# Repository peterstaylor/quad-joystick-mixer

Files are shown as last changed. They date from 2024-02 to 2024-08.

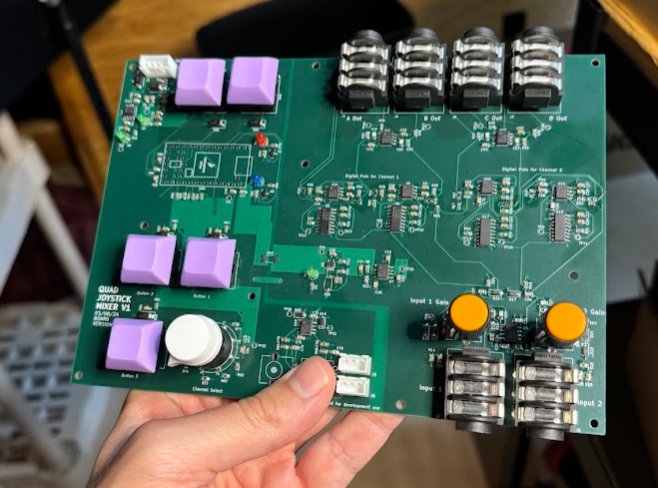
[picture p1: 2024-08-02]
mixer.png

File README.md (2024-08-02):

# quad-joystick-mixer
This is a README for the quadrophonic joystick mixer design

# Hardware
## IO Summary: 
### Digital Interface: 
We have two I2C interfaces which is more than we techincally need for this board, but is how many we'll need if we go to 8 inputs to to the mixer. Each input requires two digital pots, so that's 16 total digital pots and each i2c interface can only support up to 8 digital pots

- I2C 0 controls the digital pots for input channel 1
- I2C 1 controls the digital pots for input channel 2

### Outputs: 
I included LED indicators to help in development and for general app use as needed: 
- Red LED Indicator = Teensy Digital Output 2
- Blue LED Indicator = Teensy Digital Output 3

### Inputs: 
#### Buttons: 
There are three buttons that can be used however needed. Three might be more than we actually need, but I had spare I/O
- Button 1 = Teensy Digital Input 7
- Button 2 = Teensy Digital Input 8
- Button 3 = Teensy Digital Input 7

I've also bought out the PROGRAM and POWER pins on the Teensy to buttons. I don't think we need these, but I wasn't sure so I included them in this first revision. 

#### Analaog Inputs: 
- Encoder channel selection input = Teensy Analog Input 14
    - I used an analog input for channel selection instead of something digital so I could save I/O on the micro. If this interface is flaky we can switch to digital for the next spin of the board
- Joystick AB Control Input = Teensy Analog Input 15
- Joystick CD Control Input = Teensy Analog Input 20 

## V1 to V2 Change Log: 
- [] Use attenuator as front-end gain control instead of amplifier feedback gain
- [] Add additional filtering to VCC and VDD rails 
- [] upgrade to lower noise op-amps
- [] don't route the dang i2c nets over a cut in the ground plane!!! 
- [] Add analog filtering and buffering to the input path from the encoder to smoothe out readings
- [] revisit output gain and mixing
- [] Add six more analog inputs for a total of 8 inputs 
- [] Perform electromechanical integration work once the design is working

# Firmware
## Teensy 
- Link to Teensy tutorial: https://www.pjrc.com/teensy/tutorial.html
- Link to how to set up a portable install of the Arduino IDE: https://docs.arduino.cc/software/ide-v1/tutorials/PortableIDE/
    - I had to set up a portable install to get all the teensy libraries to install correctly and compile the code

## Board Level Test (BLT) Code
This code is written to exercise the I/O on the system in a simple way just to verify the hardware

### Major Board Level Test Functions: 
- checkBLTTransition(): 
    - This function looks for the user to press down button 1 for a certain amount of time and then puts the board in BLT mode
- flash(): 
    - flashes both LEDs the desired number of times
    - input argument is an int setting the number of flashes
- analogReadToChannelCount: 
    - input argument is an int return from reading the encoder ADC channel
    - output is the channel of the mixer 1 through 8
    - use this function to determine what channel the user is trying to control
- binaryLED: 
    - input is int of channel count 
    - i used this for BLT to verify i was iterating through the channels visually
- calibrateJoystick: 
    - I'm not using this function right now but will probably be useful for application as I've already seen that there are inconsistencies between the two joysticks I have

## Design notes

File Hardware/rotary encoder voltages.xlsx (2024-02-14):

Step | 0.4125 |  | Pull Up | 10000
Input | Voltage | Pull-down |  | Selected (kOhms) |  | 2% toleranced | Max Voltage Cutoff
1 | 0.4125 | 1428.571429 |  | 1.43 | 1.4586 | 1458.6 | 0.4275291777 | 0.4275291777
2 | 0.825 | 3333.333333 |  | 3.32 | 3.3864 | 3386.4 | 0.8474731542 | 0.4199439765
3 | 1.2375 | 6000 |  | 6.04 | 6.1608 | 6160.8 | 1.273785775 | 0.426312621
4 | 1.65 | 10000 |  | 10 | 10.2 | 10200 | 1.683 | 0.4092142249
5 | 2.0625 | 16666.66667 |  | 16.5 | 16.83 | 16830 | 2.085580173 | 0.4025801727
6 | 2.475 | 30000 |  | 30.1 | 30.702 | 30702 | 2.501520913 | 0.4159407398
7 | 2.8875 | 70000 |  | 71.5 | 72.93 | 72930 | 2.90908981 | 0.4075688977
8 | 3.3 | Open
rotary logic
if voltage is less than | the channel is | 1% resistor value
0.428 V | 1 | 1.43 kOhm
0.847 V | 2 | 3.32 kOhm
1.274 V | 3 | 6.04 kOhm
1.683 V | 4 | 10.00 kOhm
2.086 V | 5 | 16.50 kOhm
2.502 V | 6 | 30.10 kOhm
2.909 V | 7 | 71.50 kOhm
3.300 V | 8 | Open

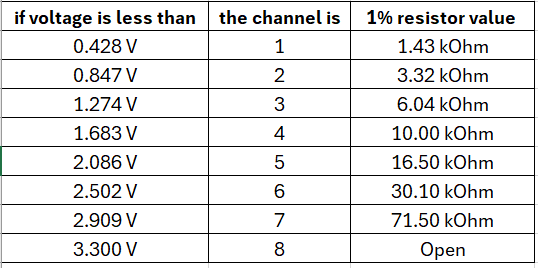
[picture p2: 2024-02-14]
Hardware/rotary.png

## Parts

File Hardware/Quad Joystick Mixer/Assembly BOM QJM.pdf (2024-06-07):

Reference | Qty | Value | Footprint
C1, C10, C26, C29, C75, C76 | 6 10uF | | 0805
C2, C5, C8, C9, C11, C13, C16, C30, C31, C34-C36, C38-C44, C53, C54, C56, C57, C60, C62, C63, C67-C74, C77, C78, C80-C86 | 43 0.1uF | | 0805
C25, C27 | 2 10pF | | 0805
C3, C4, C6, C12, C15, C24, C28, C32, C33, C37, C45-C48, C55, C58, C59, C65, C66 | 19 1uF | | 0805
C49-C52 | 4 330pF | | 0805
D1, D5 | 2 B350 | | SMA
D12-D15 | 4 MMSZ5222BT1G | | SOD-123
D16, D17 | 2 BZT52C4V7-13-F | | SOD-123
D18, D19 | 2 DDZ9684-7 | | SOD-123
D22-D26 | 5 SMAJ5.0A | | SMA
D7, D9, D11, D20, D21 | 5 LED | | 3.0mm LED
J1 | 1 XH-B4B-XH | | JST-4
J2-J7 | 6 NMJ6HCD | | NMJ6HCD
J8, J9 | 2 XH-A | | JST-3
NT1 | 1 NetTie_2 | | Net tie
Q1, Q2 | 2 2N7002 | | SOT-23
R14, R19, R24, R28-R31, R48, R50, R53, R58, R61 | 12 100k | | 0805
R15, R18, R66-R69 | 6 4.7k | | 0805
R16, R17 | 2 470R | | 0805
R20 | 1 4.7R | | 0805
R3 | 1 3k | | 0805
R34, R35, R38, R39 | 4 1k | | 0805
R40, R85-R88 | 5 DNA | | -- mixed values --
R62 | 1 1.43k | | 0805
R63 | 1 3.32k | | 0805
R64, R65 | 2 100R | | 0805
R73 | 1 6.04k | | 0805
R75 | 1 16.5k | | 0805
R76 | 1 30.1k | | 0805
R77 | 1 71.5k | | 0805
R78, R80 | 2 200R | | 0805
R8, R23, R32, R33, R36, R37 | 6 20k | | 0805
R9, R11, R21, R22, R25-R27, R44-R47, R49, R51, R52, R56, R57, R59, R60, R72, R74, R79, R81-R84 | 25 10k | | 0805
RV1, RV2 | 2 500kA | | 9mm pot
RV3, RV4 | 2 10k-B | | 9mm pot

Reference | Qty | Value | Footprint
SW2 | 1 Stompbox 1P8T Rotary | | 1p8t rotary
SW3-SW7 | 5 Cherry MX | | Cherry MX
TP1-TP23 | 23 TestPoint | | TP
U1 | 1 L78M12ACDT-TR | | TO-252-2
U2 | 1 MC79L12ABDG | | SOIC-8
U20 | 1 Teensy4.0 | | Teensy
U4, U6, U7, U10-U12, U14, U16, U19 | 9 TL072 | | SOIC-8
U5 | 1 MCP1755T-5002E/OT | | SOT-23-5
U8, U9, U13, U17 | 4 DS1881Z-050+ | | SOIC-16

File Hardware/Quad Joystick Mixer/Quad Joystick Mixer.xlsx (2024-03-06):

Assembly Count | 1
Reference | Value | Qty | Ext Qty | Footprint | Current | DK PN | MPN | Power | Source | V | Unit Cost | Ext Cost
C1, C7, C10, C21, C26, C29, C75, C76 | 10uF | 8 | 8 | Capacitor_SMD:C_0805_2012Metric_Pad1.18x1.45mm_HandSolder |  | 490-GRM21BR61H106KE43KCT-ND | GRM21BR61H106KE43K |  | DK |  | 0.224 | 1.792
C2, C8, C9, C11, C16, C19, C20, C22, C30, C31, C34-C36, C38-C44, C53, C54, C56, C57, C60, C62, C63, C67-C74, C77, C78, C80-C86 | 0.1uF | 44 | 44 | Capacitor_SMD:C_0805_2012Metric_Pad1.18x1.45mm_HandSolder |  | 1276-1003-1-ND | CL21B104KBCNNNC |  | DK |  | 0.024 | 1.056
C3, C4, C12, C13 | 2200uF | 4 | 4 | Capacitor_THT:C_Radial_D16.0mm_H25.0mm_P7.50mm |  | 1189-2266-ND | 35ZLH2200MEFC16X25 |  | DK | 50V | 1.63 | 6.52
C5, C14 | 100uF | 2 | 2 | Capacitor_THT:CP_Radial_D8.0mm_P3.50mm |  | 1189-2327-ND | 50ZLH100MEFC8X11.5 |  | DK | 50V | 0.39 | 0.78
C6, C15, C24, C28, C32, C33, C37, C45-C48, C55, C58, C59, C65, C66 | 1uF | 16 | 16 | Capacitor_SMD:C_0805_2012Metric_Pad1.18x1.45mm_HandSolder |  | 1276-1029-1-ND | CL21B105KBFNNNE |  | DK | -- mixed values -- | 0.075 | 1.2
C17, C18 | 22uF | 2 | 2 | Capacitor_SMD:C_1206_3216Metric_Pad1.33x1.80mm_HandSolder |  | 445-8045-1-ND | C3216X5R1V226M160AC |  | DK |  | 0.86 | 1.72
C23 | 100pF | 1 | 1 | Capacitor_SMD:C_0805_2012Metric_Pad1.18x1.45mm_HandSolder |  | 1276-1014-1-ND | CL21C101JBANNNC |  | DK |  | 0.1 | 0.1
C25, C27 | 10pF | 2 | 2 | Capacitor_SMD:C_0805_2012Metric_Pad1.18x1.45mm_HandSolder |  | 399-C0805C100J5GAC7800CT-ND | C0805C100J5GAC7800 |  | DK | 50V | 0.1 | 0.2
C49-C52 | 330pF | 4 | 4 | Capacitor_SMD:C_0805_2012Metric_Pad1.18x1.45mm_HandSolder |  | 399-C0805C331J5GAC7800CT-ND | C0805C331J5GAC7800 |  | DK |  | 0.1 | 0.4
D1-D6, D10 | B350 | 7 | 7 | Diode_SMD:D_SMA_Handsoldering |  | B350A-FDICT-ND | B350A-13-F |  | DK |  | 0.377 | 2.639
D12-D15 | MMSZ5222BT1G | 4 | 4 | Diode_SMD:D_SOD-123 |  | MMSZ5222BT1GOSCT-ND | MMSZ5222BT1G |  | DK |  | 0.23 | 0.92
D16, D17 | BZT52C4V7-13-F | 2 | 2 | Diode_SMD:D_SOD-123 |  | BZT52C4V7-13FDICT-ND | BZT52C4V7-13-F |  | DK |  | 0.21 | 0.42
D18, D19 | DDZ9684-7 | 2 | 2 | Diode_SMD:D_SOD-123 |  | DDZ9684-7DICT-ND | DDZ9684-7 |  | DK |  | 0.28 | 0.56
D22-D26 | SMAJ5.0A | 5 | 5 | Diode_SMD:D_SMA |  | SMAJ5.0A-FDICT-ND | SMAJ5.0A-13-F |  | DK |  | 0.39 | 1.95
L4 | 10uH | 1 | 1 | Inductor_SMD:L_Abracon_ASPI-0630LR | 1.5A | ASPI-0630LR-100M-T15CT-ND | ASPI-0630LR-100M-T15 |  | DK |  | 0.72 | 0.72
Q1, Q2 | 2N7002 | 2 | 2 | Package_TO_SOT_SMD:SOT-23 |  | 2N7002-TPMSCT-ND | 2N7002-TP |  | DK |  | 0.17 | 0.34
R1, R2, R6, R7 | 0.5R | 4 | 4 | Resistor_SMD:R_2512_6332Metric_Pad1.40x3.35mm_HandSolder |  | CSRN2512FKR500CT-ND | CSRN2512FKR500 | 2W | DK |  | 0.5 | 2
R3, R10 | 3k | 2 | 2 | Resistor_SMD:R_0805_2012Metric_Pad1.20x1.40mm_HandSolder |  | A126368CT-ND | CRG0805F3K0 |  | DK |  | 0.1 | 0.2
R4 | 270R | 1 | 1 | Resistor_SMD:R_0805_2012Metric_Pad1.20x1.40mm_HandSolder |  | 311-270CRCT-ND | RC0805FR-07270RL |  | DK |  | 0.1 | 0.1
R5 | 2.32k | 1 | 1 | Resistor_SMD:R_0805_2012Metric_Pad1.20x1.40mm_HandSolder |  | RMCF0805FT2K32CT-ND | RMCF0805FT2K32 |  | DK |  | 0.1 | 0.1
R8, R23, R32, R33, R36, R37 | 20k | 6 | 6 | Resistor_SMD:R_0805_2012Metric_Pad1.20x1.40mm_HandSolder |  | RMCF0805FT20K0CT-ND | RMCF0805FT20K0 |  | DK |  | 0.02 | 0.12
R9, R11, R21, R22, R25-R27, R44-R47, R49, R51, R52, R56, R57, R59, R60, R72, R74, R79, R81-R84 | 10k | 25 | 25 | Resistor_SMD:R_0805_2012Metric_Pad1.20x1.40mm_HandSolder |  | RMCF0805JT10K0CT-ND | RMCF0805JT10K0 |  | DK |  | 0.0104 | 0.26
R12 | 158k | 1 | 1 | Resistor_SMD:R_0805_2012Metric_Pad1.20x1.40mm_HandSolder |  | 311-158KCRCT-ND | RES 158K OHM 1% 1/8W 0805 |  | DK |  | 0.1 | 0.1
R13 | 30k | 1 | 1 | Resistor_SMD:R_0805_2012Metric_Pad1.20x1.40mm_HandSolder |  | RMCF0805JT30K0CT-ND | RMCF0805JT30K0 |  | DK |  | 0.1 | 0.1
R14, R19, R24, R28-R31, R48, R50, R53, R58, R61 | 100k | 12 | 12 | Resistor_SMD:R_0805_2012Metric_Pad1.20x1.40mm_HandSolder |  | RMCF0805FT100KCT-ND | RMCF0805FT100K |  | DK |  | 0.02 | 0.24
R15, R18, R66-R69 | 4.7k | 6 | 6 | Resistor_SMD:R_0805_2012Metric_Pad1.20x1.40mm_HandSolder |  | RMCF0805JT4K70CT-ND | RMCF0805JT4K70 |  | DK |  | 0.017 | 0.102
R16, R17 | 470 | 2 | 2 | Resistor_SMD:R_0805_2012Metric_Pad1.20x1.40mm_HandSolder |  | RMCF0805FT470RCT-ND | RMCF0805FT470R |  | DK |  | 0.1 | 0.2
R20 | 4.7R | 1 | 1 | Resistor_SMD:R_2010_5025Metric_Pad1.40x2.65mm_HandSolder |  | RMCF2010FT4R70CT-ND | RMCF2010FT4R70 | 3/4W | DK |  | 0.22 | 0.22
R34, R35, R38, R39 | 1k | 4 | 4 | Resistor_SMD:R_0805_2012Metric_Pad1.20x1.40mm_HandSolder |  | RMCF0805FT1K00CT-ND | RMCF0805FT1K00 |  | DK |  | 0.1 | 0.4
R62 | 1.43k | 1 | 1 | Resistor_SMD:R_0805_2012Metric_Pad1.20x1.40mm_HandSolder |  | 311-1.43KCRCT-ND | RC0805FR-071K43L |  | DK |  | 0.1 | 0.1
R63 | 3.32k | 1 | 1 | Resistor_SMD:R_0805_2012Metric_Pad1.20x1.40mm_HandSolder |  | RMCF0805FT3K32CT-ND | RMCF0805FT3K32 |  | DK |  | 0.1 | 0.1
R64, R65 | 100 | 2 | 2 | Resistor_SMD:R_0805_2012Metric_Pad1.20x1.40mm_HandSolder |  | 311-100CRCT-ND | RC0805FR-07100RL |  | DK |  | 0.1 | 0.2
R73 | 6.04k | 1 | 1 | Resistor_SMD:R_0805_2012Metric_Pad1.20x1.40mm_HandSolder |  | RMCF0805FT6K04CT-ND | RMCF0805FT6K04 |  | DK |  | 0.1 | 0.1
R75 | 16.5k | 1 | 1 | Resistor_SMD:R_0805_2012Metric_Pad1.20x1.40mm_HandSolder |  | RMCF0805FT16K5CT-ND | RMCF0805FT16K5 |  | DK |  | 0.1 | 0.1
R76 | 30.1k | 1 | 1 | Resistor_SMD:R_0805_2012Metric_Pad1.20x1.40mm_HandSolder |  | RMCF0805FT30K1CT-ND | RMCF0805FT30K1 |  | DK |  | 0.1 | 0.1
R77 | 71.5k | 1 | 1 | Resistor_SMD:R_0805_2012Metric_Pad1.20x1.40mm_HandSolder |  | RMCF0805FT71K5CT-ND | RMCF0805FT71K5 |  | DK |  | 0.1 | 0.1
R78, R80 | 200 | 2 | 2 | Resistor_SMD:R_0805_2012Metric_Pad1.20x1.40mm_HandSolder |  | RMCF0805FT200RCT-ND | RMCF0805FT200R | .125 W | DK |  | 0.1 | 0.2
SW3-SW7 | Cherry MX | 5 | 5 | Button_Switch_Keyboard:SW_Cherry_MX_1.00u_PCB |  | CH160-ND | MX1A-11NW |  | DK |  | 0.886 | 4.43
U1 | LM338-TO-220 | 1 | 1 | Package_TO_SOT_THT:TO-220-3_Vertical |  | LM338T/NOPB-ND | LM338T/NOPB |  | DK |  | 2.34 | 2.34
U2 | LM2990T-12/NOPB | 1 | 1 | Package_TO_SOT_THT:TO-220-3_Vertical |  | LM2990T-12/NOPB-ND | LM2990T-12/NOPB |  | DK |  | 3.13 | 3.13
U3 | AP63200WU | 1 | 1 | Package_TO_SOT_SMD:TSOT-23-6 |  | AP63200WU-7 | AP63200WU-7DICT-ND |  | DK |  | 0.87 | 0.87
U4, U6, U7, U10-U12, U14, U16, U19 | TL072 | 9 | 9 | Package_SO:SOIC-8_3.9x4.9mm_P1.27mm |  | 296-TL072HIDRCT-ND | TL072HIDR |  | DK |  | 0.299 | 2.691
U5 | MCP1755T-5002E/OT | 1 | 1 | Package_TO_SOT_SMD:SOT-23-5_HandSoldering |  | MCP1755T-5002E/OT | MCP1755T-5002E/OTCT-ND |  | DK |  | 0.69 | 0.69
U8, U9, U13, U17 | DS1881Z-050+ | 4 | 4 | Package_SO:SOIC-16_3.9x9.9mm_P1.27mm |  | DS1881Z-050+-ND | DS1881Z-050+ |  | DK |  | 3.27 | 13.08
PS1 |  | 1 | 1 |  |  | 237-1885-ND | WAU16-2400 |  | DK |  | 27.77 | 27.77
PCB |  | 1 | 1 |  |  |  |  |  | JLCPCB |  |  | 40
NT1 | NetTie_2 | 1 | 1 | NetTie:NetTie-2_SMD_Pad2.0mm |  |  |  |  | NA |  |  | 0
R40 | DNA | 1 | 1 | Resistor_SMD:R_2010_5025Metric_Pad1.40x2.65mm_HandSolder |  |  |  |  | NA |  |  | 0
R85-R88 | DNA | 4 | 4 | Resistor_SMD:R_0805_2012Metric_Pad1.20x1.40mm_HandSolder |  | NA | NA |  | NA |  |  | 0
TP1-TP23 | TestPoint | 23 | 23 | TestPoint:TestPoint_THTPad_D1.5mm_Drill0.7mm |  |  |  |  | NA |  |  | 0
D7-D9, D11, D20, D21 | LED | 6 | 6 | LED_THT:LED_D3.0mm_FlatTop |  |  |  |  | SBP |  |  | 3
J1 | Barrel_Jack_Switch | 1 | 1 | Eyewool Connectors:Love My Switches 2.1MM PCB Mount DC Jack |  |  |  |  | SBP |  | 0.45 | 0.45
J2-J7 | NMJ6HCD | 6 | 6 | Eyewool Connectors:NMJ6HCD |  |  |  |  | SBP |  | 1.75 | 10.5
J8, J9 | XH-A | 2 | 2 | Connector_JST:JST_XH_B3B-XH-AM_1x03_P2.50mm_Vertical |  |  |  |  | SBP |  |  | 1.2
J8, J9 | XH-A |  |  |  |  |  |  |  | SBP |  |  | 0.08
RV1, RV2 | 500kA | 2 | 2 | Eyewool Pots:StomboxParts_9MM |  |  |  |  | SBP |  | 0.95 | 1.9
KV1, KV2 | Knob | 2 | 2 |  |  |  |  |  | SBP |  | 0.5 | 1
RV3, RV4 | 10k-B | 2 | 2 | Eyewool Pots:StomboxParts_9MM |  |  | Joystick |  | SBP |  | 0.95 | 1.9
JS1 | Joystick | 1 | 1 |  |  |  |  |  | SBP |  | 10 | 10
SW1 | SW_DPDT_x2 | 1 | 1 | Eyewool Switches:Taiway DPDT |  |  |  |  | SBP |  | 1.1 | 1.1
SW2 | Stompbox 1P8T Rotary | 1 | 1 | Eyewool Switches:Stompbox 1P8T Rotary |  |  |  |  | SBP |  | 1.5 | 1.5
SW3-SW7 | MX Keycaps | 5 | 5 |  |  |  |  |  | TBD |  |  | 6
U20 | Teensy4.0 | 1 | 1 | teensy:Teensy40 |  |  |  |  | Teensy |  | 23.8 | 23.8
 |  |  |  |  |  |  |  |  |  |  |  | 17.25
 |  |  |  |  |  |  |  |  |  |  | parts | 201.14
 |  |  |  |  |  |  |  |  |  |  | shipping | 50
 |  |  |  |  |  |  |  |  |  |  | adder % | 10
 |  |  |  |  |  |  |  |  |  |  |  | 276.254

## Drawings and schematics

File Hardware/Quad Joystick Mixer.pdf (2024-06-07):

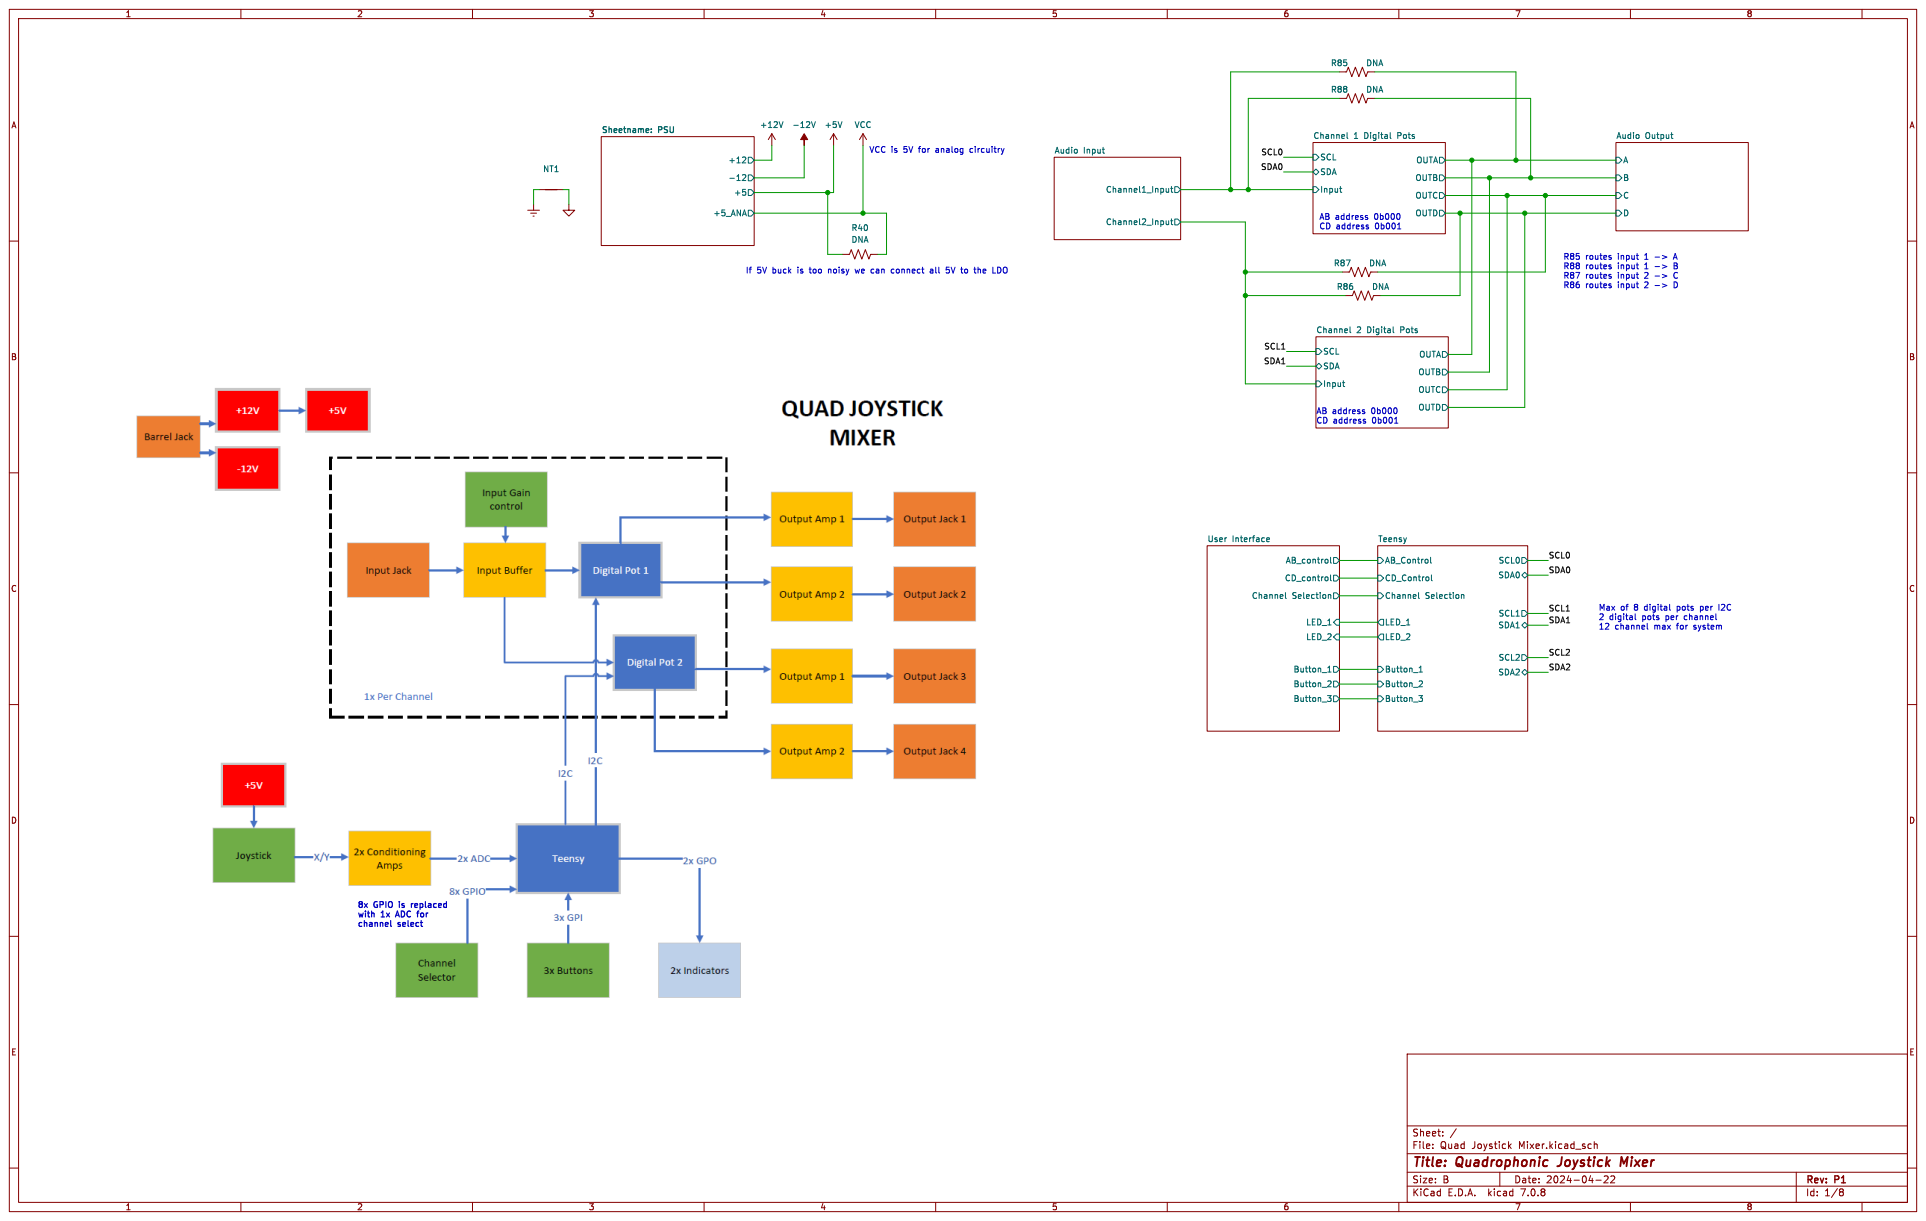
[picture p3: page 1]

Audio Output CD_control AB_control Channel Selection

If 5V buck is too noisy we can connect all 5V to the LDO

AB address 0b000 CD address 0b001

8x GPIO is replaced with 1x ADC for channel select

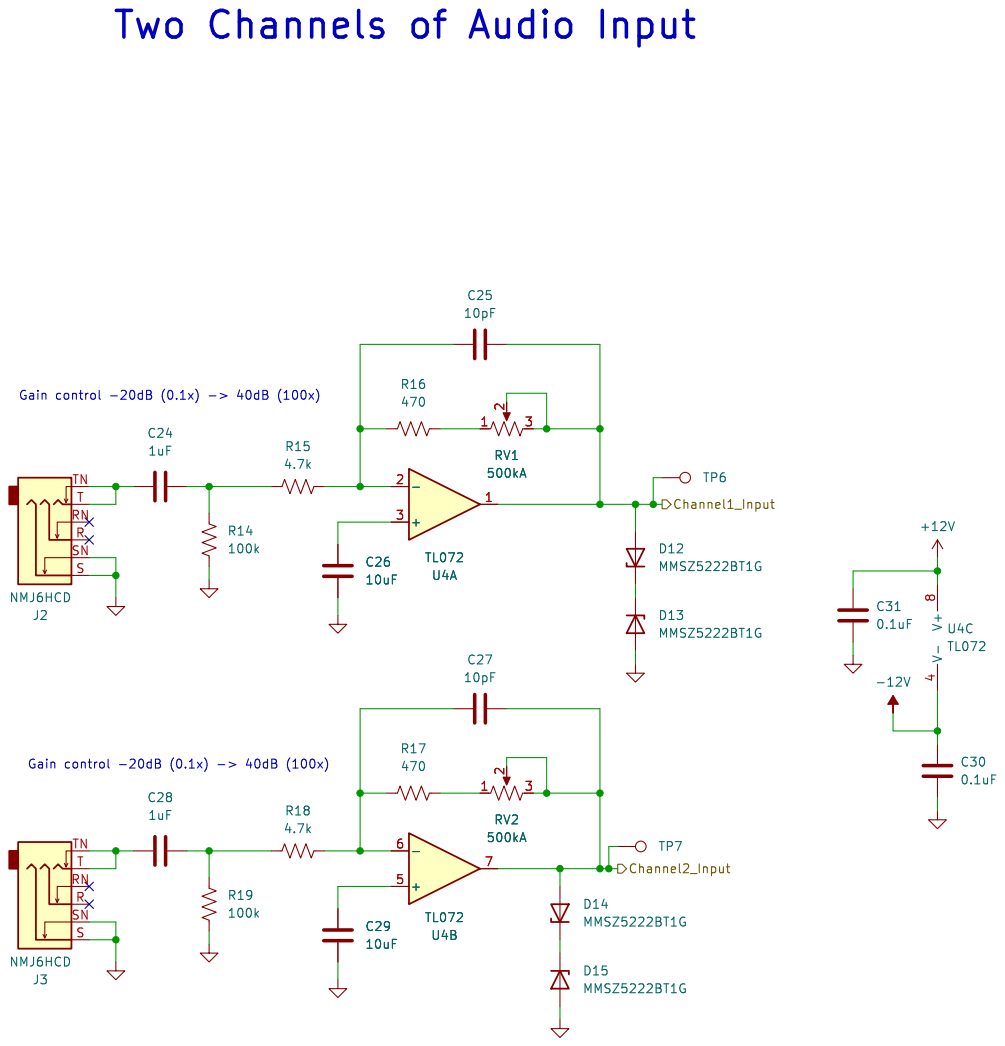
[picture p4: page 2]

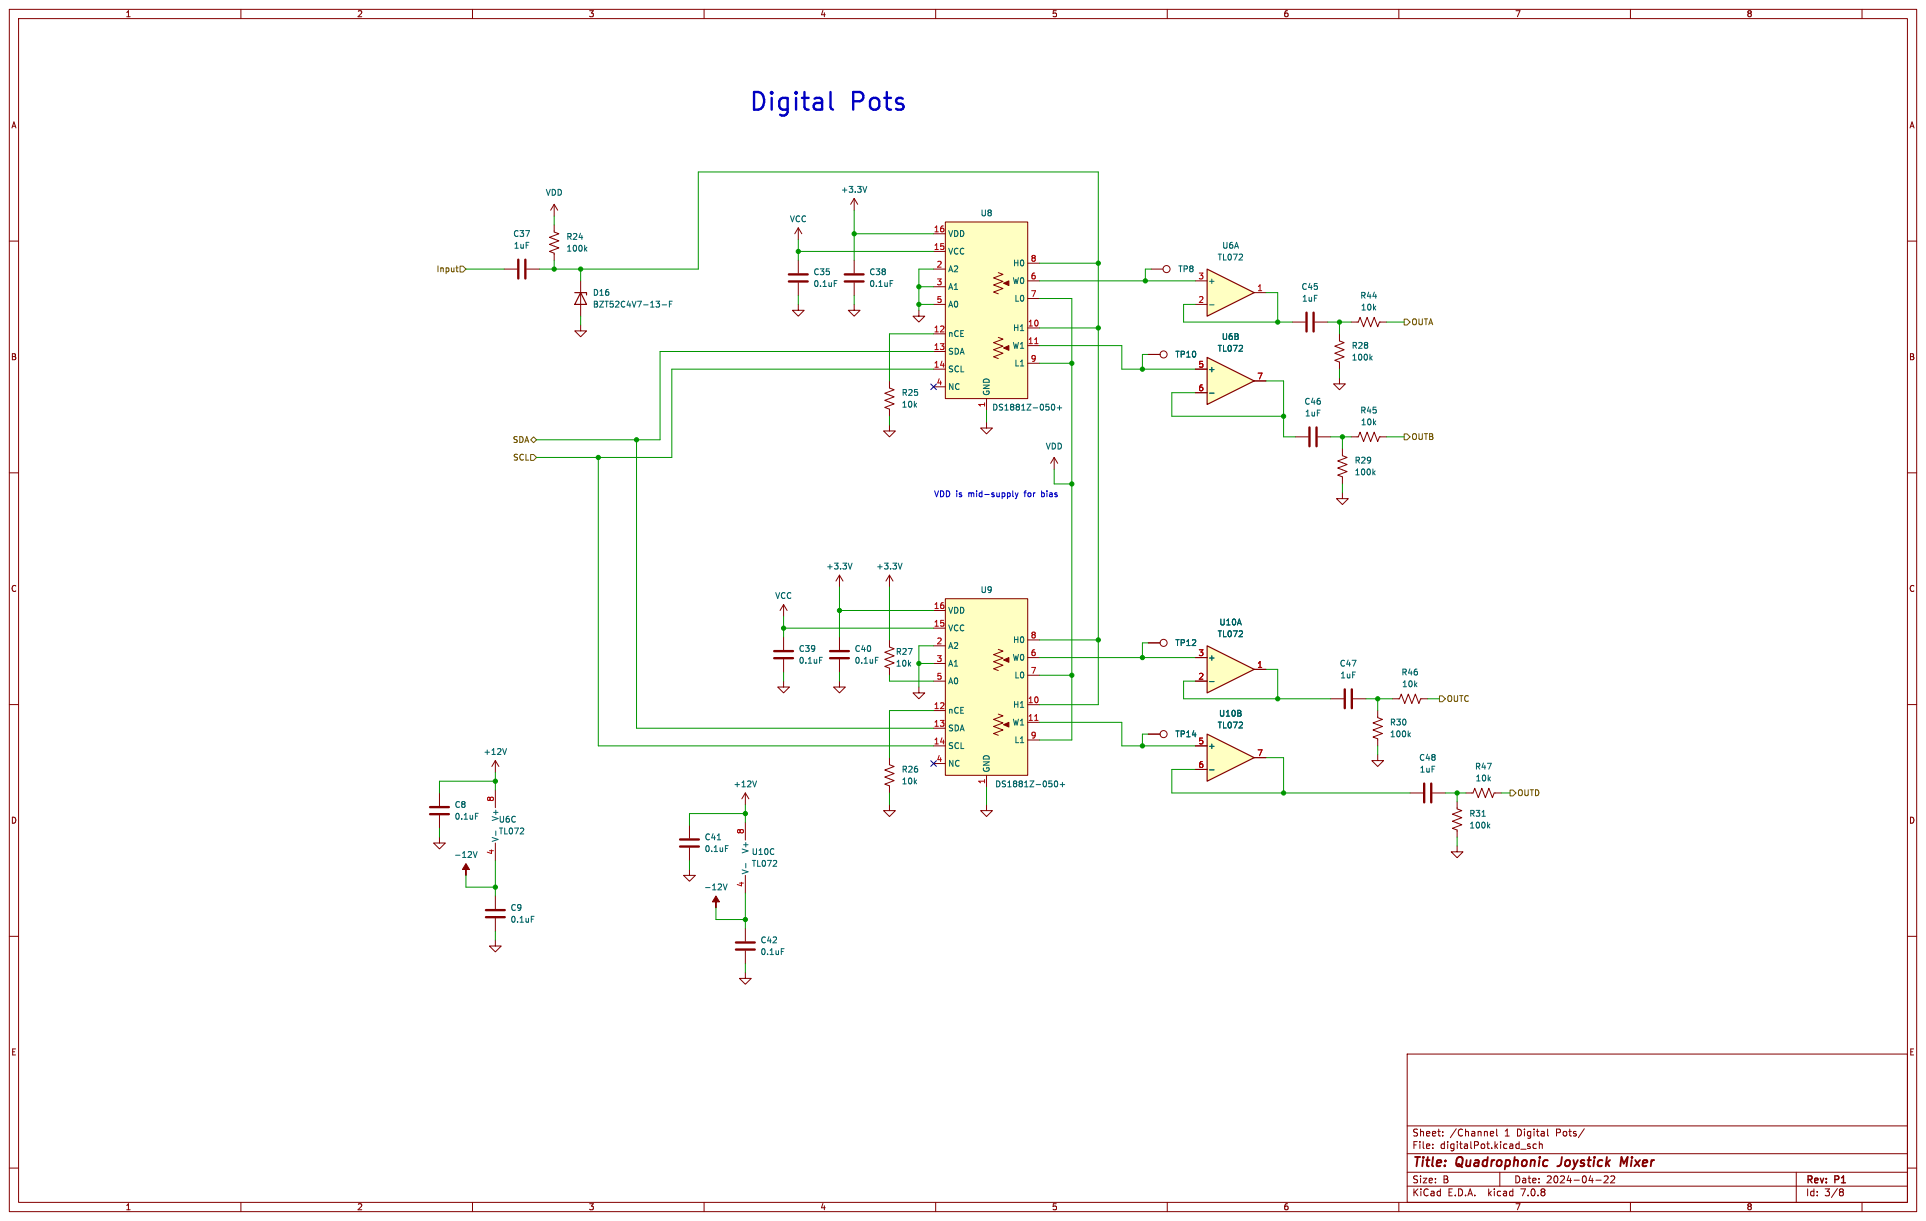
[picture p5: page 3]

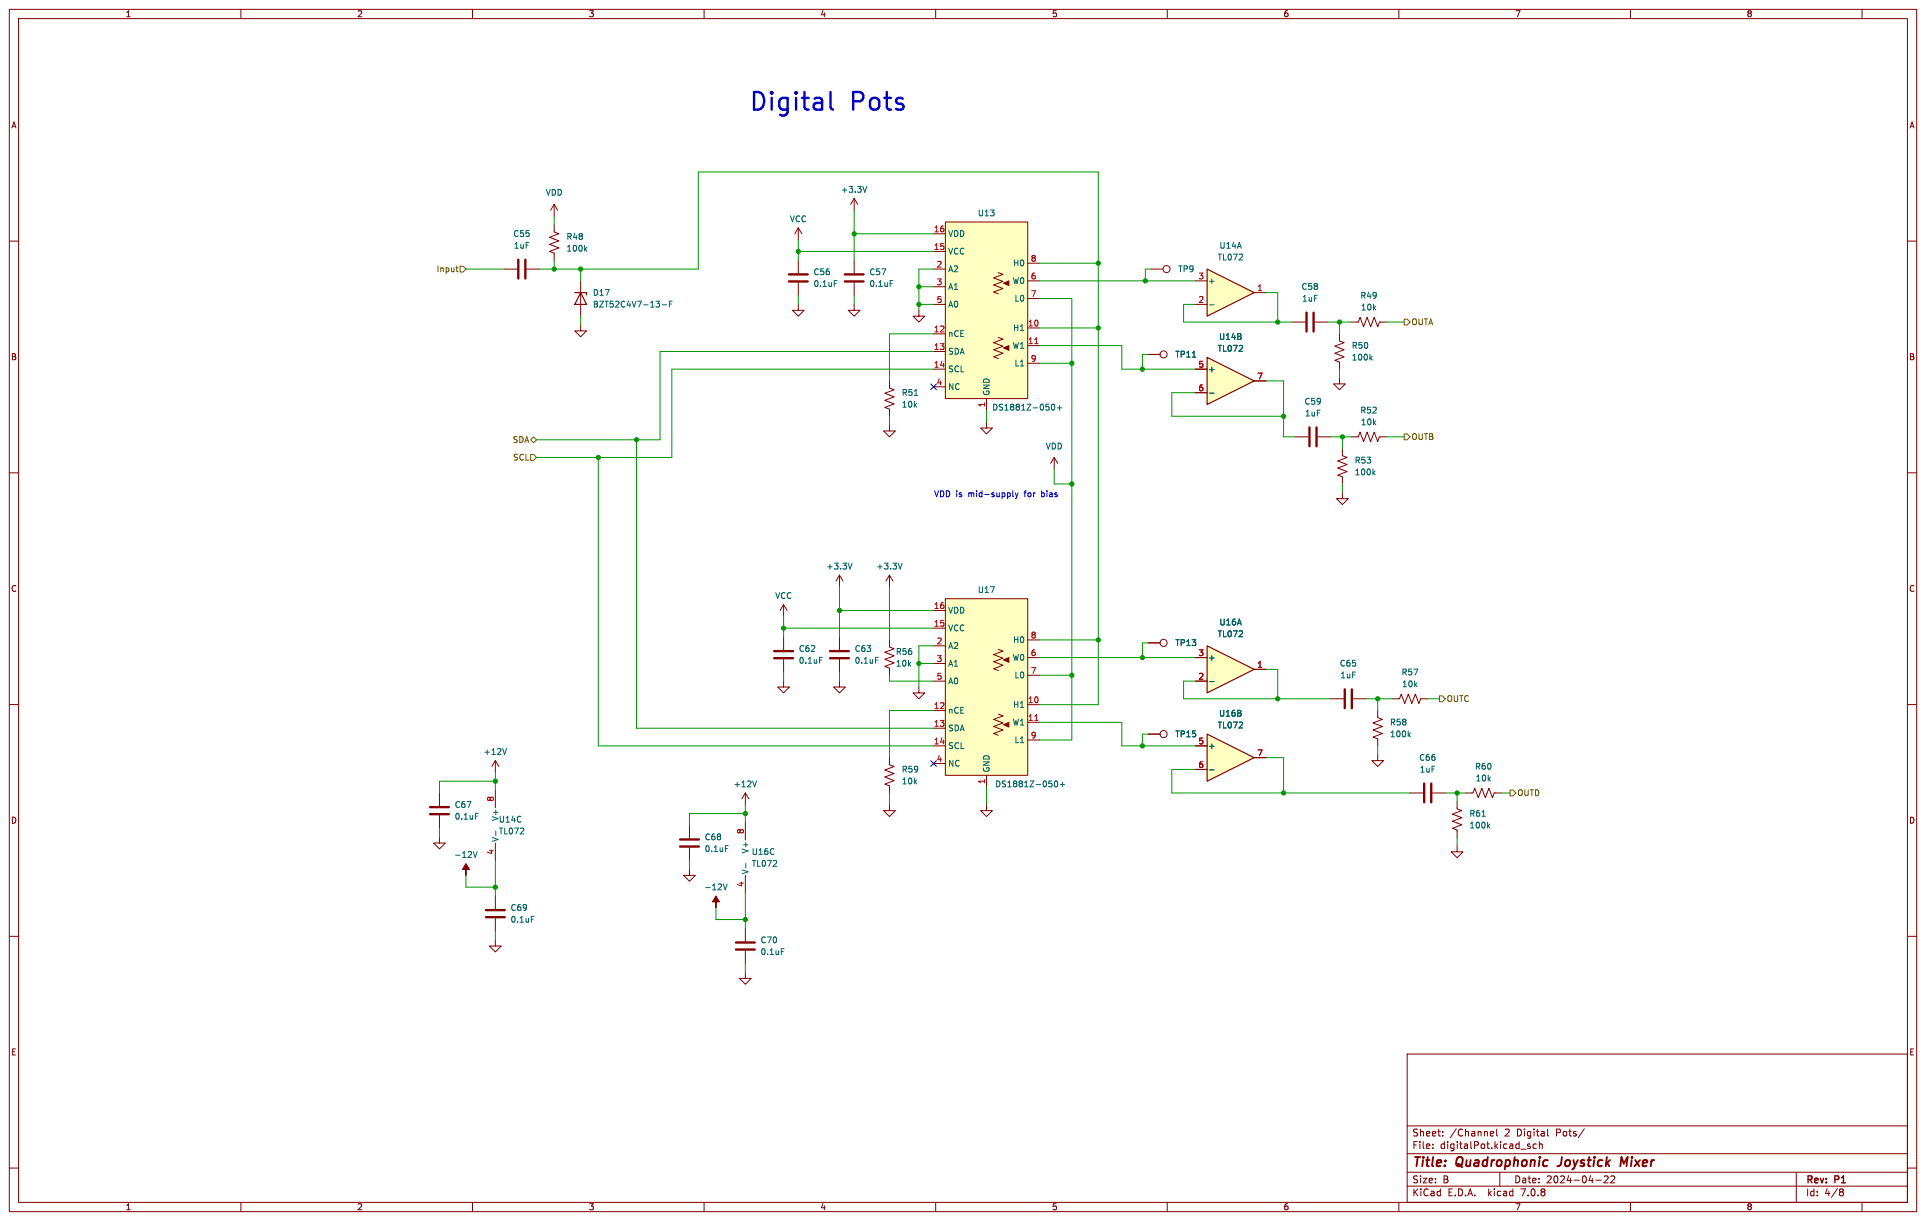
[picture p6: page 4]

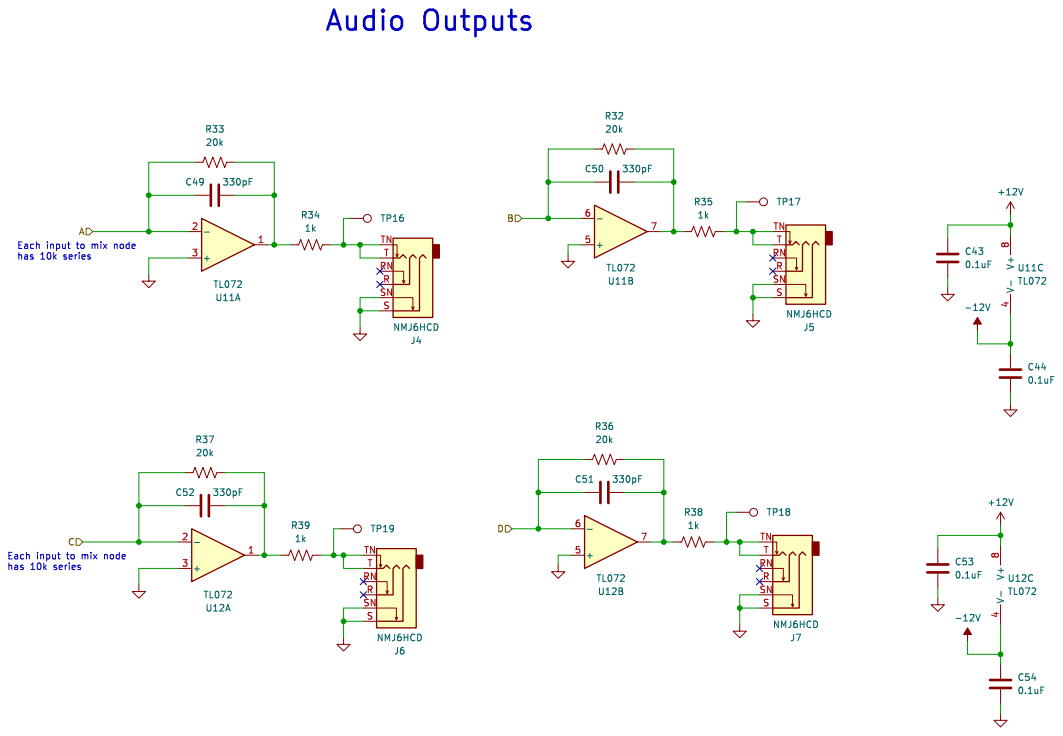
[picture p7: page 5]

Each input to mix node
has 10k series

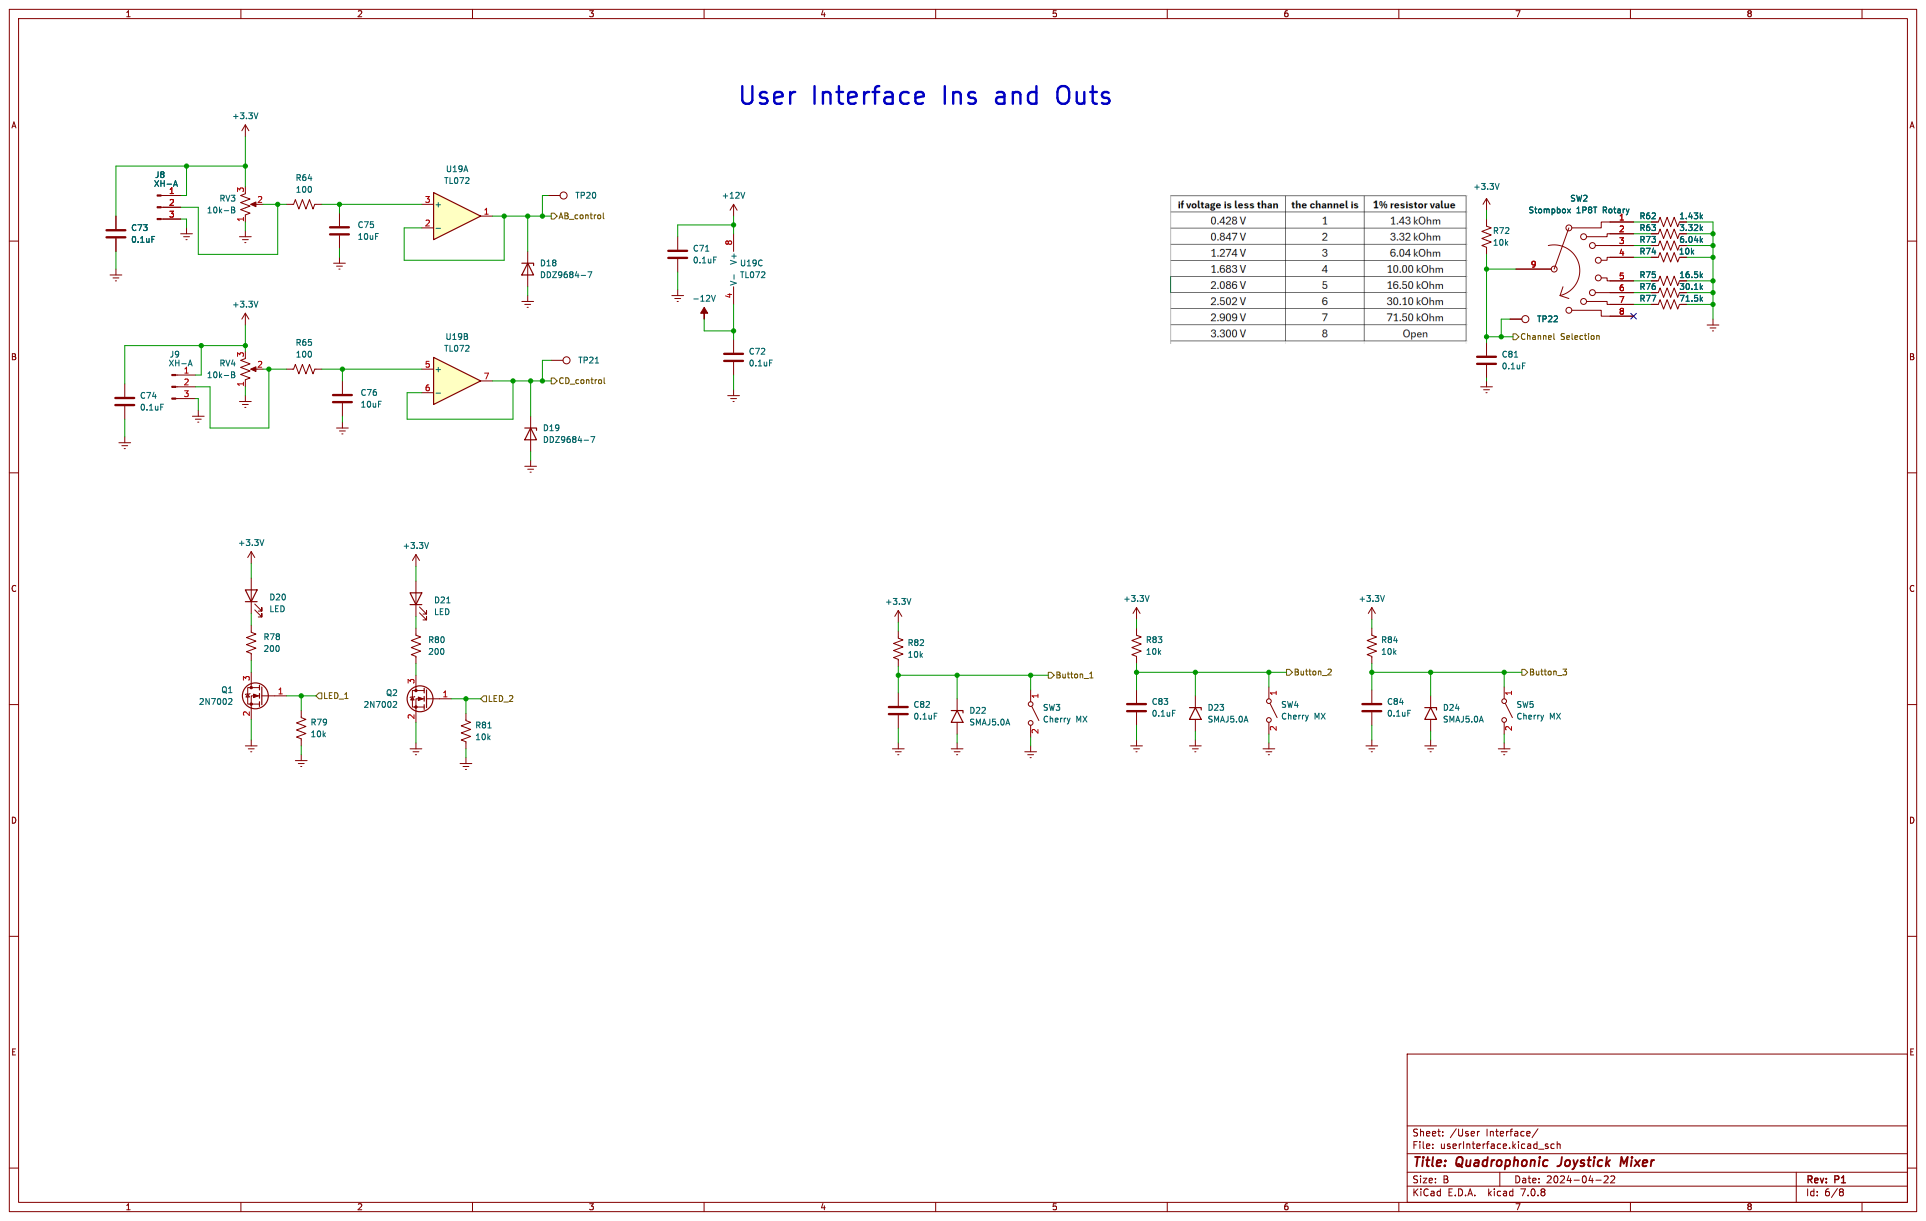
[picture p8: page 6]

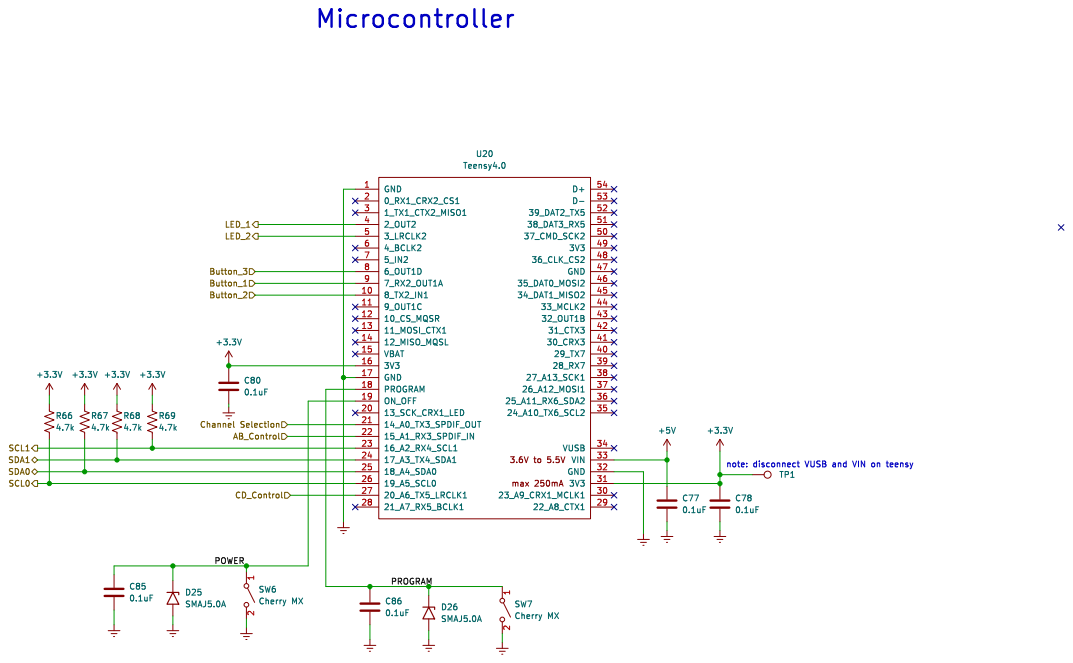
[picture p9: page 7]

Id: 7/8 Title: Quadrophonic Joystick Mixer File: teensy.kicad_sch Sheet: /Teensy/ C77

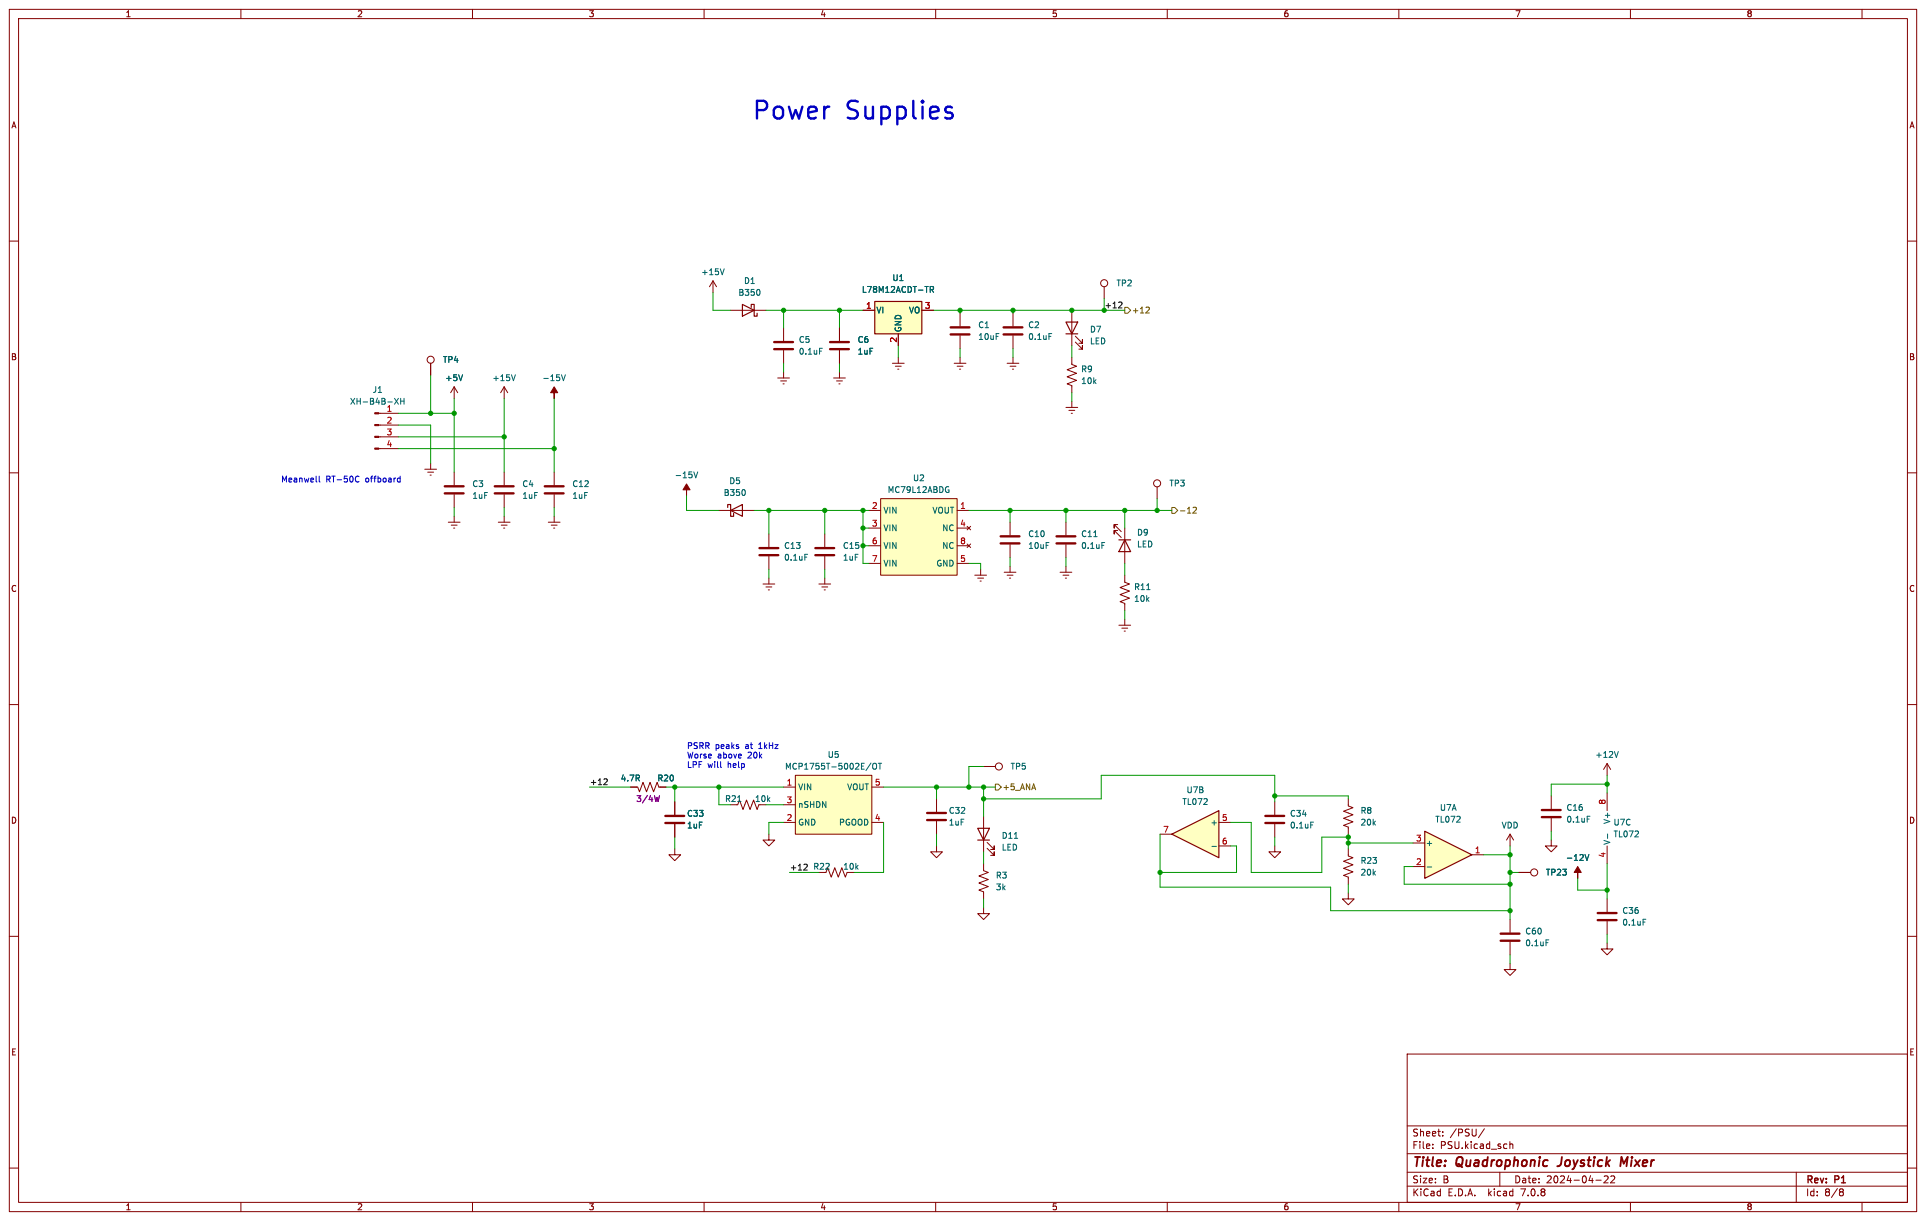
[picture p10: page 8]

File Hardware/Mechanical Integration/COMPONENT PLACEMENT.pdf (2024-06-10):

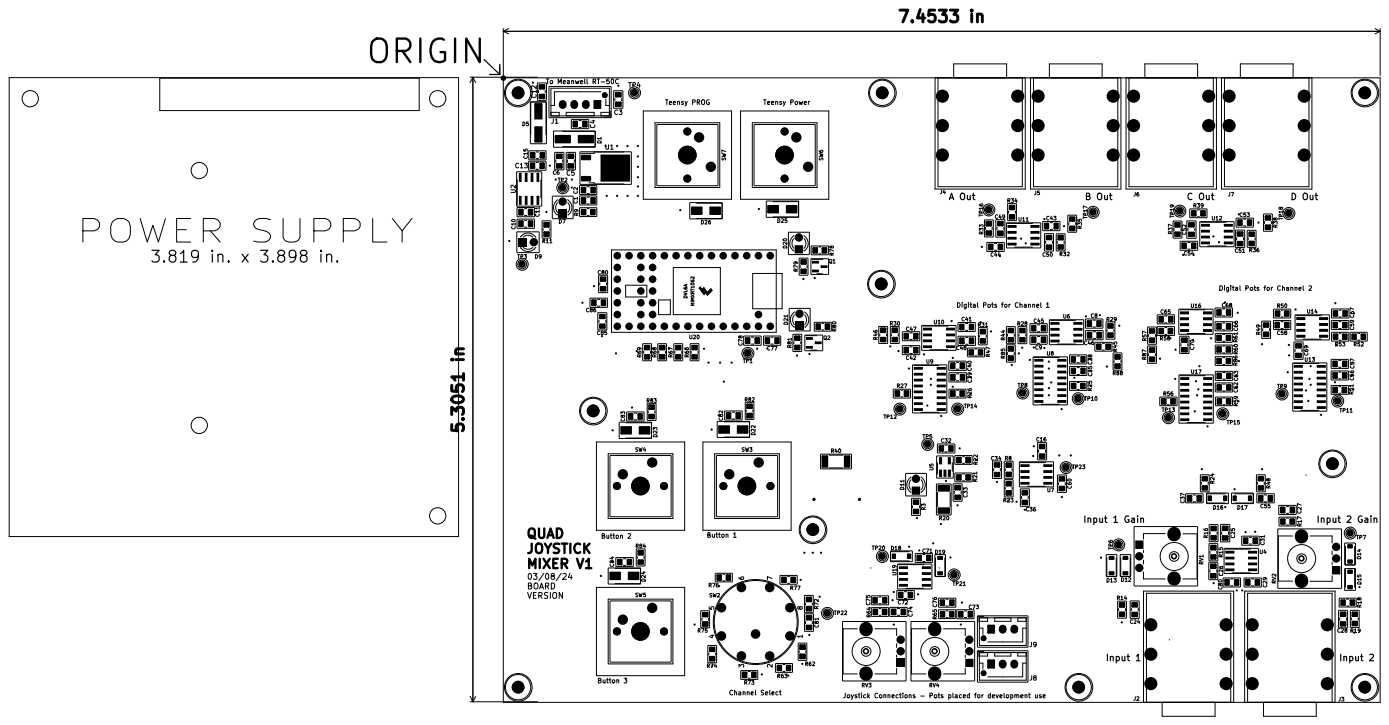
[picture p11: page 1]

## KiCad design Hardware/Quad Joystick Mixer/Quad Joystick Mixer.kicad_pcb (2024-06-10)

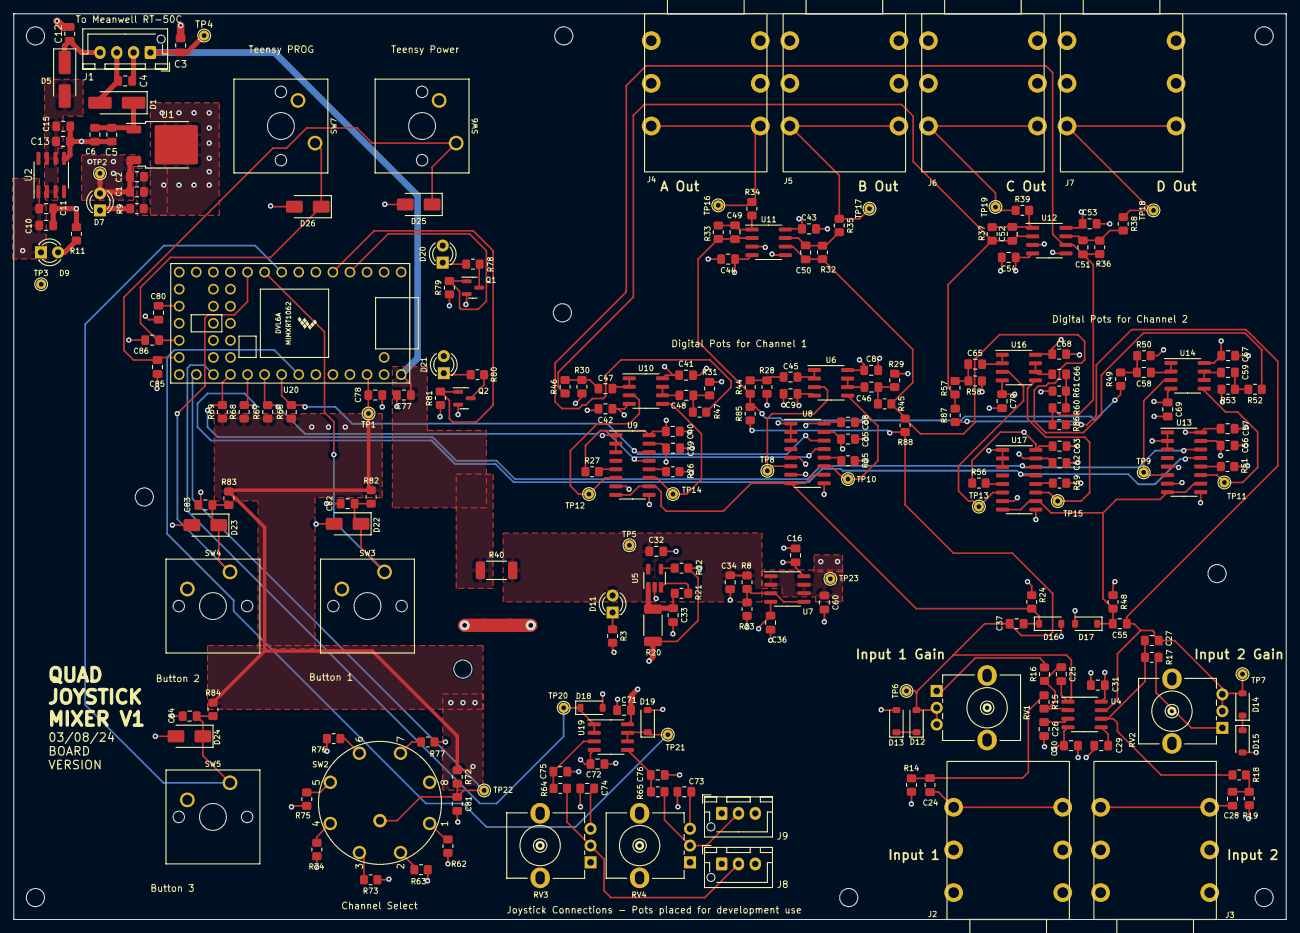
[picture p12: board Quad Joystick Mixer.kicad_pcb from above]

Board: 4 copper layers, 189.3 x 134.8 mm, 228 parts (0 on the bottom side), 106 nets.

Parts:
C1, C10, C26, C29, C75, C76: 10uF; C_0805_2012Metric_Pad1.18x1.45mm_HandSolder
C2, C5, C8, C9, C11, C13, C16, C30, C31, C34, C35, C36, C38, C39, C40, C41, C42, C43, C44, C53, C54, C56, C57, C60, C62, C63, C67, C68, C69, C70, C71, C72, C73, C74, C77, C78, C80, C81, C82, C83, C84, C85, C86: 0.1uF; C_0805_2012Metric_Pad1.18x1.45mm_HandSolder
C3, C4, C6, C12, C15, C24, C28, C32, C33, C37, C45, C46, C47, C48, C55, C58, C59, C65, C66: 1uF; C_0805_2012Metric_Pad1.18x1.45mm_HandSolder
C25, C27: 10pF; C_0805_2012Metric_Pad1.18x1.45mm_HandSolder
C49, C50, C51, C52: 330pF; C_0805_2012Metric_Pad1.18x1.45mm_HandSolder
D1, D5: B350; D_SMA_Handsoldering
D7, D9, D11, D20, D21: LED; LED_D3.0mm_FlatTop
D12, D13, D14, D15: MMSZ5222BT1G; D_SOD-123
D16, D17: BZT52C4V7-13-F; D_SOD-123
D18, D19: DDZ9684-7; D_SOD-123
D22, D23, D24, D25, D26: SMAJ5.0A; D_SMA
J1: XH-B4B-XH; JST_XH_B4B-XH-AM_1x04_P2.50mm_Vertical
J2, J3, J4, J5, J6, J7: NMJ6HCD
J8, J9: XH-A; JST_XH_B3B-XH-AM_1x03_P2.50mm_Vertical
NT1: NetTie_2; NetTie-2_SMD_Pad2.0mm
Q1, Q2: 2N7002; SOT-23
R3: 3k; R_0805_2012Metric_Pad1.20x1.40mm_HandSolder
R8, R23, R32, R33, R36, R37: 20k; R_0805_2012Metric_Pad1.20x1.40mm_HandSolder
R9, R11, R21, R22, R25, R26, R27, R44, R45, R46, R47, R49, R51, R52, R56, R57, R59, R60, R72, R74, R79, R81, R82, R83, R84: 10k; R_0805_2012Metric_Pad1.20x1.40mm_HandSolder
R14, R19, R24, R28, R29, R30, R31, R48, R50, R53, R58, R61: 100k; R_0805_2012Metric_Pad1.20x1.40mm_HandSolder
R15, R18, R66, R67, R68, R69: 4.7k; R_0805_2012Metric_Pad1.20x1.40mm_HandSolder
R16, R17: 470; R_0805_2012Metric_Pad1.20x1.40mm_HandSolder
R20: 4.7R; R_2010_5025Metric_Pad1.40x2.65mm_HandSolder
R34, R35, R38, R39: 1k; R_0805_2012Metric_Pad1.20x1.40mm_HandSolder
R40: DNA; R_2010_5025Metric_Pad1.40x2.65mm_HandSolder
R62: 1.43k; R_0805_2012Metric_Pad1.20x1.40mm_HandSolder
R63: 3.32k; R_0805_2012Metric_Pad1.20x1.40mm_HandSolder
R64, R65: 100; R_0805_2012Metric_Pad1.20x1.40mm_HandSolder
R73: 6.04k; R_0805_2012Metric_Pad1.20x1.40mm_HandSolder
R75: 16.5k; R_0805_2012Metric_Pad1.20x1.40mm_HandSolder
R76: 30.1k; R_0805_2012Metric_Pad1.20x1.40mm_HandSolder
R77: 71.5k; R_0805_2012Metric_Pad1.20x1.40mm_HandSolder
R78, R80: 200; R_0805_2012Metric_Pad1.20x1.40mm_HandSolder
R85, R86, R87, R88: DNA; R_0805_2012Metric_Pad1.20x1.40mm_HandSolder
RV1, RV2: 500kA; StomboxParts_9MM
RV3, RV4: 10k-B; StomboxParts_9MM
SW2: Stompbox 1P8T Rotary
SW3, SW4, SW5, SW6, SW7: Cherry MX; SW_Cherry_MX_1.00u_PCB
TP1, TP2, TP3, TP4, TP5, TP6, TP7, TP8, TP9, TP10, TP11, TP12, TP13, TP14, TP15, TP16, TP17, TP18, TP19, TP20, TP21, TP22, TP23: TestPoint; TestPoint_THTPad_D1.5mm_Drill0.7mm
U1: L78M12ACDT-TR; TO-252-2
U2: MC79L12ABDG; SOIC-8_3.9x4.9mm_P1.27mm
U4, U6, U7, U10, U11, U12, U14, U16, U19: TL072; SOIC-8_3.9x4.9mm_P1.27mm
U5: MCP1755T-5002E/OT; SOT-23-5_HandSoldering
U8, U9, U13, U17: DS1881Z-050+; SOIC-16_3.9x9.9mm_P1.27mm
U20: Teensy4.0; Teensy40

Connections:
+3.3V: C38.1, C40.1, C57.1, C63.1, C73.1, C74.1, C78.1, C80.1, D20.2 (A), D21.2 (A), J8.1, J9.1, R27.1, R56.1, R66.1, R67.1, R68.1, R69.1, R72.1, R82.2, R83.2, R84.2, RV3.3, RV4.3, TP1.1, U8.16 (VDD), U9.16 (VDD), U13.16 (VDD), U17.16 (VDD), U20.16 (3V3), U20.31 (3V3)
+5V: C3.1, C77.1, J1.1, R40.1, TP4.1, U20.33 (VIN)
+12V: C1.1, C2.1, C8.1, C16.1, C31.1, C41.1, C43.1, C53.1, C67.1, C68.1, C71.1, D7.2 (A), R20.2, R22.1, TP2.1, U1.3 (VO), U4.8 (V+), U6.8 (V+), U7.8 (V+), U10.8 (V+), U11.8 (V+), U12.8 (V+), U14.8 (V+), U16.8 (V+), U19.8 (V+)
+15V: C4.1, D1.2 (A), J1.3
-12V: C9.1, C10.1, C11.1, C30.1, C36.1, C42.1, C44.1, C54.1, C69.1, C70.1, C72.1, D9.1 (K), TP3.1, U2.1 (VOUT), U4.4 (V-), U6.4 (V-), U7.4 (V-), U10.4 (V-), U11.4 (V-), U12.4 (V-), U14.4 (V-), U16.4 (V-), U19.4 (V-)
-15V: C12.1, D5.1 (K), J1.4
/Audio Input/Channel1_Input: C25.2, C37.1, D12.2 (A), R85.1, R88.1, RV1.2, RV1.3, TP6.1, U4.1
/Audio Input/Channel2_Input: C27.2, C55.1, D14.2 (A), R86.1, R87.1, RV2.2, RV2.3, TP7.1, U4.7
/Audio Output/A: C49.1, R33.2, R44.1, R49.1, R85.2, U11.2 (-)
/Audio Output/B: C50.1, R32.2, R45.1, R52.1, R88.2, U11.6 (-)
/Audio Output/C: C52.1, R37.2, R46.1, R57.1, R87.2, U12.2 (-)
/Audio Output/D: C51.1, R36.2, R47.1, R60.1, R86.2, U12.6 (-)
/SCL0: R66.2, U8.14 (SCL), U9.14 (SCL), U20.26 (19_A5_SCL0)
/SCL1: R69.2, U13.14 (SCL), U17.14 (SCL), U20.23 (16_A2_RX4_SCL1)
/SDA0: R67.2, U8.13 (SDA), U9.13 (SDA), U20.25 (18_A4_SDA0)
/SDA1: R68.2, U13.13 (SDA), U17.13 (SDA), U20.24 (17_A3_TX4_SDA1)
/Teensy/AB_Control: D18.1 (K), TP20.1, U19.1, U19.2 (-), U20.22 (15_A1_RX3_SPDIF_IN)
/Teensy/Button_1: C82.1, D22.1 (A1), R82.1, SW3.1 (A), U20.9 (7_RX2_OUT1A)
/Teensy/Button_2: C83.1, D23.1 (A1), R83.1, SW4.1 (A), U20.10 (8_TX2_IN1)
/Teensy/Button_3: C84.1, D24.1 (A1), R84.1, SW5.1 (A), U20.8 (6_OUT1D)
/Teensy/CD_Control: D19.1 (K), TP21.1, U19.6 (-), U19.7, U20.27 (20_A6_TX5_LRCLK1)
/Teensy/Channel Selection: C81.1, R72.2, SW2.9, TP22.1, U20.21 (14_A0_TX3_SPDIF_OUT)
/Teensy/LED_1: Q1.1 (G), R79.2, U20.4 (2_OUT2)
/Teensy/LED_2: Q2.1 (G), R81.2, U20.5 (3_LRCLK2)
/Teensy/POWER: C85.1, D25.1 (A1), SW6.1 (A), U20.19 (ON_OFF)
/Teensy/PROGRAM: C86.1, D26.1 (A1), SW7.1 (A), U20.18 (PROGRAM)
Earth: C1.2, C2.2, C3.2, C4.2, C5.2, C6.2, C10.2, C11.2, C12.2, C13.2, C15.2, C71.2, C72.2, C73.2, C74.2, C75.2, C76.2, C77.2, C78.2, C80.2, C81.2, C82.2, C83.2, C84.2, C85.2, C86.2, D18.2 (A), D19.2 (A), D22.2 (A2), D23.2 (A2), D24.2 (A2), D25.2 (A2), D26.2 (A2), J1.2, J8.3, J9.3, NT1.1, Q1.2 (S), Q2.2 (S), R9.2, R11.2, R62.2, R63.2, R73.2, R74.2, R75.2, R76.2, R77.2, R79.1, R81.1, RV3.1, RV4.1, SW3.2 (B), SW4.2 (B), SW5.2 (B), SW6.2 (B), SW7.2 (B), U1.2 (GND), U2.5 (GND), U20.1 (GND), U20.17 (GND), U20.32 (GND)
GND: C8.2, C9.2, C16.2, C26.2, C29.2, C30.2, C31.2, C32.2, C33.2, C34.2, C35.2, C36.2, C38.2, C39.2, C40.2, C41.2, C42.2, C43.2, C44.2, C53.2, C54.2, C56.2, C57.2, C60.2, C62.2, C63.2, C67.2, C68.2, C69.2, C70.2, D13.2 (A), D15.2 (A), D16.2 (A), D17.2 (A), J2.S, J2.SN, J3.S, J3.SN, J4.S, J4.SN, J5.S, J5.SN, J6.S, J6.SN, J7.S, J7.SN, NT1.2, R3.2, R14.2, R19.2, R23.2, R25.2, R26.2, R28.2, R29.2, R30.2, R31.2, R50.2, R51.2, R53.2, R58.2, R59.2, R61.2, U5.2 (GND), U8.1 (GND), U8.2 (A2), U8.3 (A1), U8.5 (A0), U9.1 (GND), U9.2 (A2), U9.3 (A1), U11.3 (+), U11.5 (+), U12.3 (+), U12.5 (+), U13.1 (GND), U13.2 (A2), U13.3 (A1), U13.5 (A0), U17.1 (GND), U17.2 (A2), U17.3 (A1)
unnamed: C24.1, J2.T, J2.TN
unnamed: C24.2, R14.1, R15.1
unnamed: C28.1, J3.T, J3.TN
unnamed: C28.2, R18.1, R19.1
unnamed: C45.2, R28.1, R44.2
unnamed: C46.2, R29.1, R45.2
unnamed: C47.2, R30.1, R46.2
unnamed: C48.2, R31.1, R47.2
unnamed: C49.2, R33.1, R34.2, U11.1
unnamed: C50.2, R32.1, R35.2, U11.7
unnamed: C51.2, R36.1, R38.2, U12.7
unnamed: C52.2, R37.1, R39.2, U12.1
unnamed: C58.2, R49.2, R50.1
unnamed: C59.2, R52.2, R53.1
unnamed: C65.2, R57.2, R58.1
unnamed: C66.2, R60.2, R61.1
unnamed: C5.1, C6.1, D1.1 (K), U1.1 (VI)
unnamed: C13.1, C15.1, D5.2 (A), U2.2 (VIN), U2.3 (VIN), U2.6 (VIN), U2.7 (VIN)
unnamed: D7.1 (K), R9.1
unnamed: D9.2 (A), R11.1
unnamed: D11.1 (K), R3.1
unnamed: D12.1 (K), D13.1 (K)
unnamed: D14.1 (K), D15.1 (K)
unnamed: C37.2, D16.1 (K), R24.2, U8.8 (H0), U8.10 (H1), U9.8 (H0), U9.10 (H1)
unnamed: C55.2, D17.1 (K), R48.2, U13.8 (H0), U13.10 (H1), U17.8 (H0), U17.10 (H1)
unnamed: D20.1 (K), R78.2
unnamed: D21.1 (K), R80.2
unnamed: J4.T, J4.TN, R34.1, TP16.1
unnamed: J5.T, J5.TN, R35.1, TP17.1
unnamed: J6.T, J6.TN, R39.1, TP19.1
unnamed: J7.T, J7.TN, R38.1, TP18.1
unnamed: J8.2, R64.1, RV3.2
unnamed: J9.2, R65.1, RV4.2
unnamed: Q1.3 (D), R78.1
unnamed: Q2.3 (D), R80.1
unnamed: R16.2, RV1.1
unnamed: R17.2, RV2.1
unnamed: R62.1, SW2.1
unnamed: R63.1, SW2.2
unnamed: R73.1, SW2.3
unnamed: R74.1, SW2.4
unnamed: R75.1, SW2.5
unnamed: R76.1, SW2.6
unnamed: R77.1, SW2.7
unnamed: C26.1, U4.3 (+)
unnamed: C25.1, R15.2, R16.1, U4.2 (-)
unnamed: C29.1, U4.5 (+)
unnamed: C27.1, R17.1, R18.2, U4.6 (-)
unnamed: R22.2, U5.4 (PGOOD)
unnamed: C33.1, R20.1, R21.1, U5.1 (VIN)
unnamed: R21.2, U5.3 (nSHDN)
unnamed: TP8.1, U6.3 (+), U8.6 (W0)
unnamed: C45.1, U6.1, U6.2 (-)
unnamed: TP10.1, U6.5 (+), U8.11 (W1)
unnamed: C46.1, U6.6 (-), U6.7
unnamed: R8.2, R23.1, U7.3 (+), U7.5 (+)
unnamed: R25.1, U8.12 (nCE)
unnamed: R27.2, U9.5 (A0)
unnamed: R26.1, U9.12 (nCE)
unnamed: TP12.1, U9.6 (W0), U10.3 (+)
unnamed: C47.1, U10.1, U10.2 (-)
unnamed: TP14.1, U9.11 (W1), U10.5 (+)
unnamed: C48.1, U10.6 (-), U10.7
unnamed: TP9.1, U13.6 (W0), U14.3 (+)
unnamed: TP11.1, U13.11 (W1), U14.5 (+)
unnamed: R51.1, U13.12 (nCE)
unnamed: C58.1, U14.1, U14.2 (-)
unnamed: C59.1, U14.6 (-), U14.7
unnamed: TP13.1, U16.3 (+), U17.6 (W0)
unnamed: C65.1, U16.1, U16.2 (-)
unnamed: TP15.1, U16.5 (+), U17.11 (W1)
unnamed: C66.1, U16.6 (-), U16.7
unnamed: R56.2, U17.5 (A0)
unnamed: R59.1, U17.12 (nCE)
unnamed: C75.1, R64.2, U19.3 (+)
unnamed: C76.1, R65.2, U19.5 (+)
VCC: C32.1, C34.1, C35.1, C39.1, C56.1, C62.1, D11.2 (A), R8.1, R40.2, TP5.1, U5.5 (VOUT), U8.15 (VCC), U9.15 (VCC), U13.15 (VCC), U17.15 (VCC)
VDD: C60.1, R24.1, R48.1, TP23.1, U7.1, U7.2 (-), U7.6 (-), U7.7, U8.7 (L0), U8.9 (L1), U9.7 (L0), U9.9 (L1), U13.7 (L0), U13.9 (L1), U17.7 (L0), U17.9 (L1)

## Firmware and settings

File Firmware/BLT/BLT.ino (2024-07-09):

#include <Wire.h>

// variables
int RED = 2;
int BLUE = 3;
int button1 = 7;
int button2 = 8;
int button3 = 6;

// channel selection variables for encoder
int encoderInput = 14;
int channelSelect = 0;

// joystick management variables
bool calibrateJoystick = false; 
int ABcontrol = 15;
int ABreading = 0;
int CDcontrol = 20;
int CDreading = 0;
int ABmax = 512;
int ABmin = 512;
int ABmid = 512;
int CDmax = 512;
int CDmin = 512;
int CDmid = 512;

// channel selection analog reading cutoffs
int channel1Cutoff = 190;
int channel2Cutoff = 319;
int channel3Cutoff = 448;
int channel4Cutoff = 574;
int channel5Cutoff = 702;
int channel6Cutoff = 832;
int channel7Cutoff = 959;

// variables for checking button 1
// used to transition to BLT mode
bool runBLT = false;
unsigned long startBLTdet = 0;
unsigned long endBLTdet = 0;
unsigned long bltOnTimeout = 2000;

// button state management
int button1State = 0;
int lastButton1State = 0;
int button2State = 0;
int lastButton2State = 0;
int button3State = 0;
int lastButton3State = 0;

// digital pot variables
char channel1ABaddr = 0x28; 
char channel1CDaddr = 0x29; 
char channel2ABaddr = 0x28; 
char channel2CDaddr = 0x29; 
// "max" volume is lowest value, "min" volume is highest value
int pot0max = 0;
int pot0mid = 31; // <-- default when joystick is centered?
int pot0min = 63; // mute setting
int pot1max = 64; 
int pot1mid = 95; // <-- default when joystick is centered? 
int pot1min = 127; // mute setting
int aStart = 0; 
int bStart = 21; 
int cStart = 42;
int dStart = 63; 
// see datasheet for details on config but: 
// pot values are stored in NVM
// zero crossing is enabled
// pot is set for 63 settings
char potConfig = 0b10000110; 



// setup function
void setup() {
  Serial.begin(38400);
  Serial.println("Beginning setup...");

  // red and blue LEDs can be used for status indication in the system
  pinMode(RED, OUTPUT);
  pinMode(BLUE, OUTPUT);

  // start I2C peripherals
  Wire.begin(); 
  Wire1.begin();   

  Serial.println("Setup complete...");
}


void loop() {
  if (runBLT) {
    boardLevelTest();
    runBLT = false;
    delay(1000);
  } else {
    checkBLTtransition();
    // app code goes here
  }
}

void boardLevelTest() {
  Serial.println("Beginning test procedure...");
  // Test 1, basic blink pattern on two LEDs
  test1();

  // Test 2, check buttons 2 and 3
  test2();

  // Test 3, checks the encoder
  test3();

  // Test 4 checks the joystick input
  test4();

  // Test 5 checks the I2c comms with the pots
  test5(); 
}

// implmenets a timeout on button 1
// if you hold down button 1 long enough, the system will switch to BLT mode
void checkBLTtransition() {
  button1State = digitalRead(button1);
  if(button1State == 1){
    startBLTdet = millis(); 
  } else{
    if(millis() - startBLTdet > bltOnTimeout){
      runBLT = true; 
    }
  }
}

void flash(int numFlash) {
  for (int i = 0; i < numFlash; i++) {
    digitalWrite(RED, HIGH);
    digitalWrite(BLUE, HIGH);
    delay(250);
    digitalWrite(RED, LOW);
    digitalWrite(BLUE, LOW);
    delay(250);
  }
  return;
}

int analogReadToChannelCount(int analogRead) {
  int channelCount;
  if (analogRead < channel1Cutoff) {
    channelCount = 1;
  } else if (analogRead < channel2Cutoff) {
    channelCount = 2;
  } else if (analogRead < channel3Cutoff) {
    channelCount = 3;
  } else if (analogRead < channel4Cutoff) {
    channelCount = 4;
  } else if (analogRead < channel5Cutoff) {
    channelCount = 5;
  } else if (analogRead < channel6Cutoff) {
    channelCount = 6;
  } else if (analogRead < channel7Cutoff) {
    channelCount = 7;
  } else {
    channelCount = 8;
  }

  return channelCount;
}

void binaryLED(int count) {
  digitalWrite(RED, LOW);
  digitalWrite(BLUE, LOW);
  if (count == 1 || count == 5) {
    digitalWrite(RED, LOW);
    digitalWrite(BLUE, LOW);
  } else if (count == 2 || count == 6) {
    digitalWrite(RED, HIGH);
    digitalWrite(BLUE, LOW);
  } else if (count == 3 || count == 7) {
    digitalWrite(RED, LOW);
    digitalWrite(BLUE, HIGH);
  } else if (count == 4 || count == 8) {
    digitalWrite(RED, HIGH);
    digitalWrite(BLUE, HIGH);
  }
  return;
}



// first test just toggles the red and blue LEDs to verify hardware connection
void test1() {
  bool proceed = false;
  Serial.println("Beginning test #1:");
  flash(1);
  Serial.println("Red and blue LEDs should be flashing quickly and opposite from each other");
  Serial.println("Press button 1 to proceed");
  while (!proceed) {
    digitalWrite(RED, HIGH);
    digitalWrite(BLUE, LOW);
    delay(100);
    digitalWrite(RED, LOW);
    digitalWrite(BLUE, HIGH);
    delay(100);
    proceed = checkToMoveOn(); 
  }

  // reset everything after test 1
  digitalWrite(RED, LOW);
  digitalWrite(BLUE, LOW);
}

// second test uses button 2 and 3 to toggle the LEDs, verifying the buttons
void test2() {
  bool proceed = false;
  Serial.println("Beginning test #2:");
  flash(2);
  Serial.println("Press button 2 to toggle red LED, button 3 to toggle blue LED");
  Serial.println("Press button 1 to proceed");
  while (!proceed) {
    button2State = digitalRead(button2);
    if (button2State != lastButton2State && button2State == 0) {
      digitalWrite(RED, !digitalRead(RED));
    }
    lastButton2State = button2State;

    button3State = digitalRead(button3);
    if (button3State != lastButton3State && button3State == 0) {
      digitalWrite(BLUE, !digitalRead(BLUE));
    }
    lastButton3State = button3State;
    proceed = checkToMoveOn(); 
  }

  // reset everything after test 2
  digitalWrite(RED, LOW);
  digitalWrite(BLUE, LOW);
}

// check the encoder
void test3() {
  int channelCount = 0;
  int lastChannelCount = 0;
  bool proceed = false;
  int repCount = 0;
  int repCutoff = 5000;
  Serial.println("Beginning test 3:");
  flash(3);
  Serial.println("Rotate encoder to cycle through binary states on LEDs");
  Serial.println("Press button 1 to proceed");
  while (!proceed) {

    channelSelect = analogRead(encoderInput);
    channelCount = analogReadToChannelCount(channelSelect);
    if (channelCount == lastChannelCount) {
      repCount++;
    } else {
      repCount = 0;
    }
    if (repCount >= repCutoff) {
      binaryLED(channelCount);
    }
    lastChannelCount = channelCount;
    proceed = checkToMoveOn(); 
  }
}

void test4() {
  bool proceed = false;
  Serial.println("Beginning test 4:");
  Serial.println("Move joystick around to control brightness of LEDs"); 
  flash(4);
  if (calibrateJoystick) {
    joystickCalibration();
  }

  proceed = false;
  delay(1000);
  while (!proceed) {
    ABreading = int(float(analogRead(ABcontrol)) / 4.0);
    CDreading = int(float(analogRead(CDcontrol)) / 4.0);
    analogWrite(RED, ABreading);
    analogWrite(BLUE, CDreading);
    proceed = checkToMoveOn(); 
    if (proceed) { 
      analogWrite(RED,0); 
      analogWrite(BLUE,0); 
      pinMode(RED, INPUT);
      pinMode(BLUE, INPUT);
      pinMode(RED, OUTPUT);
      pinMode(BLUE, OUTPUT);
    }
  }
}

void joystickCalibration() {
  bool proceed = false;
  Serial.println("Let joystick rest in middle to calibrate center measurement:");
  delay(1000);
  for (int i = 0; i < 20000; i++) {
    ABmid = (ABmid + analogRead(ABcontrol)) / 2;
    CDmid = (CDmid + analogRead(CDcontrol)) / 2;
  }
  Serial.println("Middle calibrated");
  Serial.println("now swing joystick in full circle for a few seconds");
  Serial.println("press button 1 to proceed after swinging joystick around");
  while (!proceed) {
    ABreading = analogRead(ABcontrol);
    CDreading = analogRead(CDcontrol);
    if (ABreading > ABmax) {
      ABmax = ABreading;
    } else if (ABreading < ABmin) {
      ABmin = ABreading;
    }

    if (CDreading > CDmax) {
      CDmax = CDreading;
    } else if (CDreading < CDmin) {
      CDmin = CDreading;
    }
    proceed = checkToMoveOn();
    if (proceed) {
      Serial.println("Calibration complete!");
    }
  }
}

// try to talk to the digital pots
void test5() {
  bool proceed = false;
  int output = 0; 
  Serial.println("Beginning test #5:");
  Serial.println("Hold down button 1 to proceed"); 
  flash(5); 
  configI2C();
  initialI2CCheck(); 
  while (!proceed) {
    toggleOutputs(output);  
    output++; 
    if(output == 4){
      output = 0; 
    }
    proceed = checkToMoveOn(); 
    if(proceed){
      Serial.println("Test complete!"); 
      analogWrite(RED,0); 
      analogWrite(BLUE,0); 
      delay(1000); 
    }
  }
}

// sends audio out one output at a time, changes the output every half second
void toggleOutputs(int output) {
  if (output == 0) {
    Serial.println("Send Audio out A"); 
    analogWrite(RED,0); 
    analogWrite(BLUE,0);
    Wire.beginTransmission(channel1ABaddr);
    Wire.write(pot0max);  // turn on A
    Wire.write(pot1min);  // mute B
    Wire.endTransmission();
    Wire.beginTransmission(channel1CDaddr);
    Wire.write(pot0min);  // mute C
    Wire.write(pot1min);  // mute D
    Wire.endTransmission(); 

    Wire1.beginTransmission(channel2ABaddr); 
    Wire1.write(pot0max); // turn on A
    Wire1.write(pot1min);  // mute B
    Wire1.endTransmission(); 
    Wire1.beginTransmission(channel2CDaddr); 
    Wire1.write(pot0min); // mute C
    Wire1.write(pot1min); // mute D
    Wire1.endTransmission(); 

  } else if (output == 1) {
    //Serial.println("Send Audio out B"); 
    analogWrite(RED,0); 
    analogWrite(BLUE,255);
    Wire.beginTransmission(channel1ABaddr);
    Wire.write(pot0min);  
    Wire.write(pot1max);  
    Wire.endTransmission();
    Wire.beginTransmission(channel1CDaddr);
    Wire.write(pot0min);  
    Wire.write(pot1min);  
    Wire.endTransmission(); 

    Wire1.beginTransmission(channel2ABaddr); 
    Wire1.write(pot0min); 
    Wire1.write(pot1max);  
    Wire1.endTransmission(); 
    Wire1.beginTransmission(channel2CDaddr); 
    Wire1.write(pot0min); 
    Wire1.write(pot1min); 
    Wire1.endTransmission();

  } else if (output == 2) {
    //Serial.println("Send Audio out C"); 
    analogWrite(RED,255); 
    analogWrite(BLUE,0);
    Wire.beginTransmission(channel1ABaddr);
    Wire.write(pot0min);  
    Wire.write(pot1min);  
    Wire.endTransmission();
    Wire.beginTransmission(channel1CDaddr);
    Wire.write(pot0max);  
    Wire.write(pot1min);  
    Wire.endTransmission(); 

    Wire1.beginTransmission(channel2ABaddr); 
    Wire1.write(pot0min); 
    Wire1.write(pot1min);  
    Wire1.endTransmission(); 
    Wire1.beginTransmission(channel2CDaddr); 
    Wire1.write(pot0max); 
    Wire1.write(pot1min); 
    Wire1.endTransmission();

  } else if (output == 3) {
    //Serial.println("Send Audio out D"); 
    analogWrite(RED,255); 
    analogWrite(BLUE,255);
    Wire.beginTransmission(channel1ABaddr);
    Wire.write(pot0min);  
    Wire.write(pot1min);  
    Wire.endTransmission();
    Wire.beginTransmission(channel1CDaddr);
    Wire.write(pot0min);  
    Wire.write(pot1max);  
    Wire.endTransmission(); 

    Wire1.beginTransmission(channel2ABaddr); 
    Wire1.write(pot0min); 
    Wire1.write(pot1min);  
    Wire1.endTransmission(); 
    Wire1.beginTransmission(channel2CDaddr); 
    Wire1.write(pot0min); 
    Wire1.write(pot1max); 
    Wire1.endTransmission();
  }
  delay(1000); 
  return;
}

// configures all four digital pots
void configI2C(){
  Wire.beginTransmission(channel1ABaddr); 
  Wire.write(potConfig); 
  Wire.write(pot0min); 
  Wire.write(pot1min); 
  Wire.endTransmission(); 

  Wire.beginTransmission(channel1CDaddr); 
  Wire.write(potConfig); 
  Wire.write(pot0min); 
  Wire.write(pot1min);
  Wire.endTransmission(); 

  Wire1.beginTransmission(channel2ABaddr); 
  Wire1.write(potConfig); 
  Wire1.write(pot0min); 
  Wire1.write(pot1min); 
  Wire1.endTransmission(); 

  Wire1.beginTransmission(channel2CDaddr); 
  Wire1.write(potConfig); 
  Wire1.write(pot0min); 
  Wire1.write(pot1min); 
  Wire1.endTransmission(); 

  return; 
}

// checks that pots come up with POR values
// might need to revisist after i start writing to NVM
void initialI2CCheck() {
  int testSum = 0; 
  bool testPass = true; 
  Wire.requestFrom(channel1ABaddr, 3);
  while (Wire.available()) {
    testSum += int(Wire.read()); 
  } 
  if(testSum != 324){
    Serial.println("Channel 1 AB Failed");
    testPass = false;   
  }

  testSum = 0; 
  Wire.requestFrom(channel1CDaddr, 3);
  while (Wire.available()) {
    testSum += int(Wire.read()); 
  }
  if(testSum != 324){
    Serial.println("Channel 1 CD Failed"); 
    testPass = false;  
  }

  testSum = 0; 
  Wire1.requestFrom(channel2ABaddr, 3);
  while (Wire1.available()) {
    testSum += int(Wire1.read()); 
  }
  if(testSum != 324){
    Serial.println("Channel 2 AB Failed"); 
    testPass = false;  
  }
  
  testSum = 0; 
  Wire1.requestFrom(channel2CDaddr, 3);
  while (Wire1.available()) {
    testSum += int(Wire1.read()); 
  } 
  if(testSum != 324){
    Serial.println("Channel 2 CD Failed"); 
    testPass = false;   
  }
  
  if(testPass){
      Serial.println("All digital pots passed initial check!"); 
  } else{
    Serial.println("Digital pots failed"); 
  }
  
  return; 
}

bool checkToMoveOn() {
  bool proceed = false;
  if (digitalRead(button1) == LOW) {
    proceed = true;
    Serial.println("Moving on to next test");
  }
  return proceed;
}

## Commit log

2024-02-02 start on the power supply design
    [Quad Joystick Mixer.kicad_pcb, Quad Joystick Mixer.kicad_sch]
2024-02-12 workign on draft of PSU circuit--thinking about making it onto its own board
    [Quad Joystick Mixer.kicad_sch]
2024-02-12 progress on PSU layout
    [Quad Joystick Mixer.kicad_pcb, Quad Joystick Mixer.kicad_sch]
2024-02-13 clean up power supply schematic
    [PSU.kicad_sch, Quad Joystick Mixer.kicad_pcb, Quad Joystick Mixer.kicad_sch]
2024-02-13 add image for reference to block diagram
    [Quad Joystick Mixer.kicad_sch]
2024-02-13 work on audio input circuit
    [Quad Joystick Mixer.kicad_sch, audioInput.kicad_sch]
2024-02-13 a few notes about changes
    [audioInput.kicad_sch]
2024-02-13 add analog 5V rail
    [PSU.kicad_sch, Quad Joystick Mixer.kicad_sch]
2024-02-13 more progress on schematic
    [Quad Joystick Mixer.kicad_sch, audioInput.kicad_sch, digitalPot.kicad_sch]
2024-02-13 work through digital pot circuit
    [Quad Joystick Mixer.kicad_sch, digitalPot.kicad_sch]
2024-02-13 working on finishing a draft of this dang schematic
    [Quad Joystick Mixer.kicad_sch, audioOutput.kicad_sch, digitalPot.kicad_sch]
2024-02-13 create joystick conditioning circuit
    [Quad Joystick Mixer.kicad_sch, audioOutput.kicad_sch, digitalPot.kicad_sch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]
2024-02-14 progress on schematic
    [Quad Joystick Mixer.kicad_sch, joystick.kicad_sch, teensy.kicad_sch]
2024-02-14 add in rotary circuit and some docs
    [PSU.kicad_sch, Quad Joystick Mixer.kicad_sch, audioInput.kicad_sch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]
2024-02-14 finished first draft of the schematic
    [PSU.kicad_sch, Quad Joystick Mixer.kicad_sch, audioInput.kicad_sch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]
2024-02-14 ok the draft wasn't done but now i think it is
    [PSU.kicad_sch, Quad Joystick Mixer.kicad_sch, audioInput.kicad_sch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]
2024-02-15 clean up after review, working through BOM
    [PSU.kicad_sch, Quad Joystick Mixer.kicad_sch, audioInput.kicad_sch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]
2024-02-16 finish adding parts to the BOM
    [PSU.kicad_sch, Quad Joystick Mixer.kicad_sch, audioInput.kicad_sch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]
2024-02-19 work on placement and layout
    [Quad Joystick Mixer.kicad_pcb, digitalPot.kicad_sch, teensy.kicad_sch]
2024-02-20 major layout progress
    [PSU.kicad_sch, Quad Joystick Mixer.kicad_pcb, audioOutput.kicad_sch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]
2024-02-20 more progress on layout
    [Quad Joystick Mixer.kicad_pcb, teensy.kicad_sch]
2024-02-20 more work no routing the board
    [Quad Joystick Mixer.kicad_pcb]
2024-02-21 update layout
    [Quad Joystick Mixer.kicad_pcb]
2024-02-21 three nets left to route
    [Quad Joystick Mixer.kicad_pcb]
2024-02-21 work through DRC errors
    [Quad Joystick Mixer.kicad_pcb, userInterface.kicad_sch]
2024-03-06 changed power supply design and everything re routed
    [PSU.kicad_sch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]
2024-03-06 clean up DRC results
    [Quad Joystick Mixer.kicad_pcb]
2024-06-07 add FW, updated README
    [Assembly BOM QJM.xlsx, PSU.kicad_sch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]
2024-06-10 finished basic I2C comms verification
2024-06-10 fix pot variable ranges
    [BLT.ino]
2024-06-10 add mechanical integration stuff
    [Quad Joystick Mixer.kicad_pcb, User Interface Component Placements.xlsx]
2024-07-09 fix the LED bug
    [BLT.ino]
2024-08-02 add a picture of the assembled V1 board
